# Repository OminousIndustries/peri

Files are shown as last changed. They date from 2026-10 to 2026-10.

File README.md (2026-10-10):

<h1 align="center">Peri</h1>

<p align="center"><em>Someone to talk to.</em></p>

<p align="center">
  <a href="docs/PARTS.md">Parts</a> ·
  <a href="prints/README.md">Print files</a> ·
  <a href="docs/ASSEMBLY.md">Assembly</a> ·
  <a href="device/INSTALL.md">Setup</a> ·
  <a href="docs/USE.md">Using Peri</a>
</p>

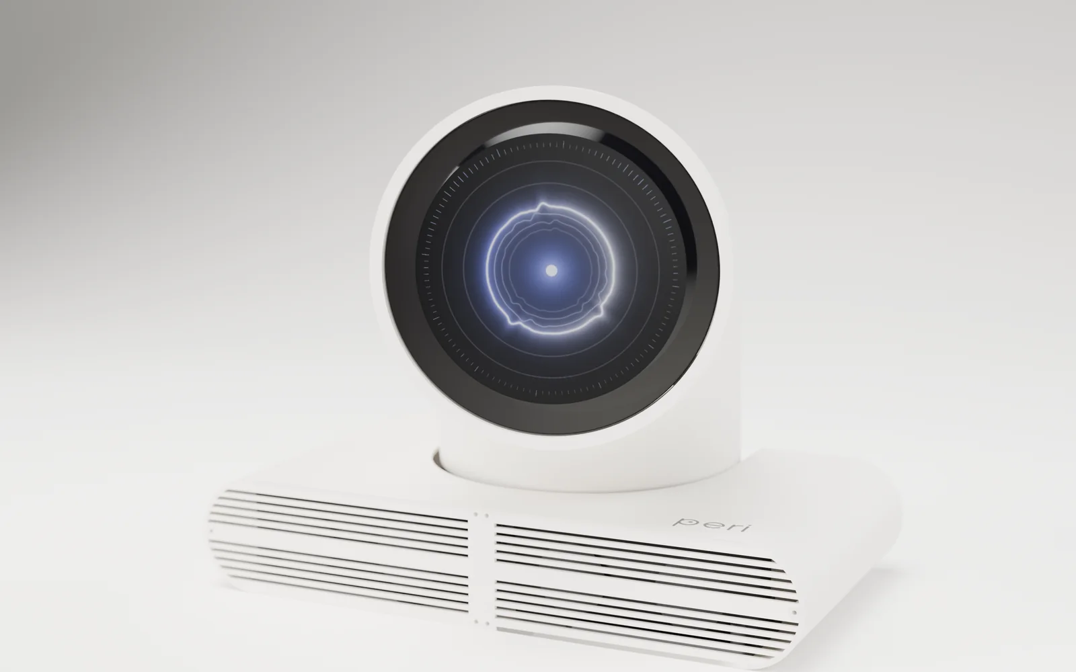
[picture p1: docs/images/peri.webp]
Product render of Peri in a warm white shell, with a glowing round display and twin speaker grilles.


<p align="center">Print it. Build it. Start a conversation.</p>

## Make it yours

Print the same case in your choice of filament. These renders show Porcelain, Graphite, Ember and Periwinkle.

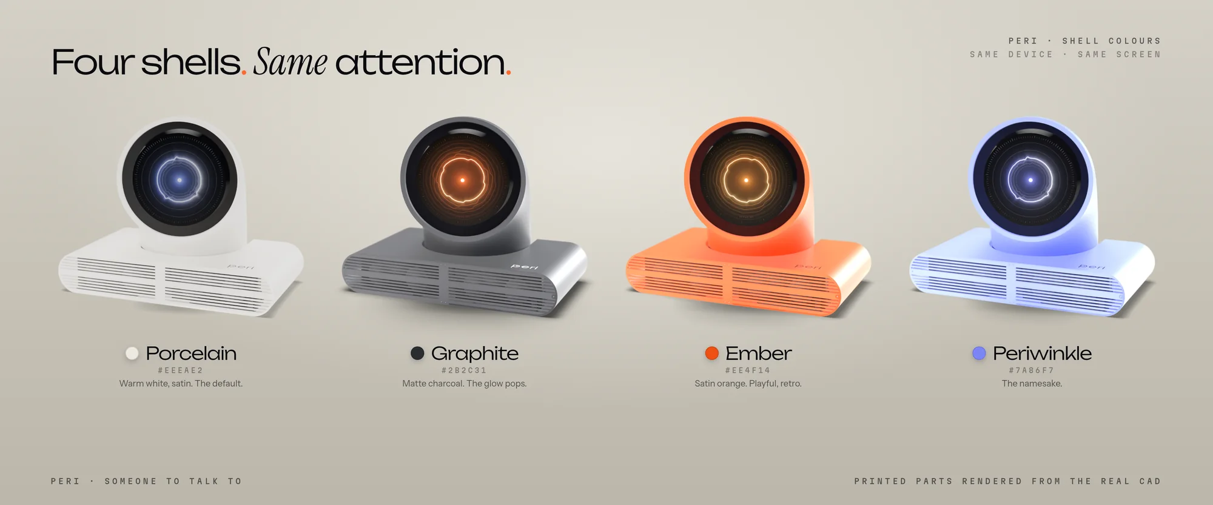
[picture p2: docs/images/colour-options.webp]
Peri rendered in four shell colours: warm white, charcoal, orange and periwinkle.


## From the inside out

An exploded render of the enclosure, neck mechanism, display and speakers. Use the [illustrated assembly guides](docs/ASSEMBLY.md) for the build sequence and wiring.

<p align="center">
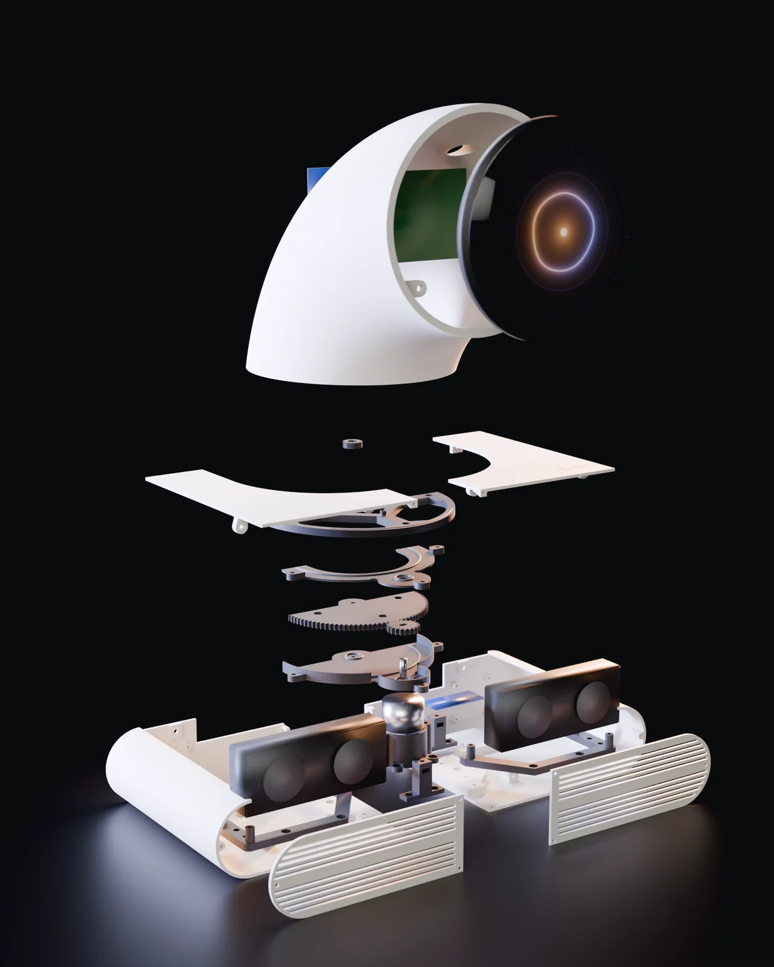
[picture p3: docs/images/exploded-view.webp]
Exploded render showing Peri's display and head shell above the neck, gears, base and two speaker enclosures.
  
</p>

## A little company

Tap the display to wake Peri and start talking. Hold it to choose a voice, adjust the volume or change its personality.

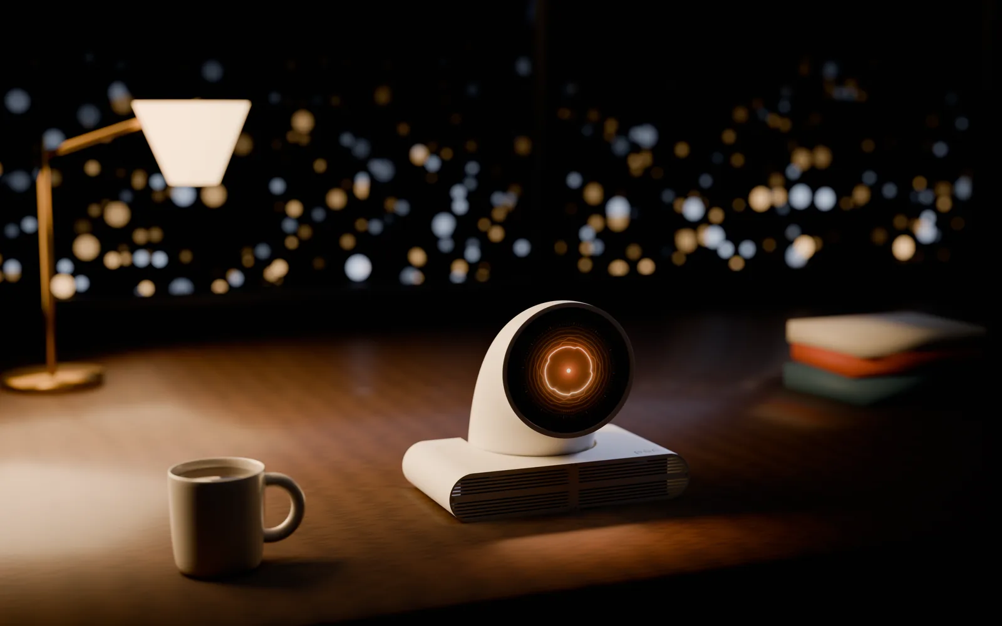
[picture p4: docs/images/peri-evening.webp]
Lifestyle render of Peri on a warmly lit desk beside a lamp, books and a mug.


*Product renders from the Peri website. Follow the assembly guides for the actual parts and wiring.*

## Build one

A 3D-printed voice chatbot built with a Raspberry Pi 4B, a round touch display and a WM8960 audio HAT with two speakers. The Arduino and motor are **optional**: the Arduino needs its own power source and does not connect to the Pi. There is no room for that USB connection inside the enclosure.

Download this repository with **Code → Download ZIP**, then follow these steps:

1. **[Get the parts](docs/PARTS.md)** — electronics, speakers, screws and tools.
2. **[Print the case](prints/README.md)** — choose the version without an Arduino, or the optional motorized version.
3. **[Assemble and wire it](docs/ASSEMBLY.md)** — follow the [main illustrated guide](docs/AssemblyGuide.pdf); use the [Arduino mounting guide](docs/ArduinoAssemblyGuide.pdf) only for the optional motor assembly.
4. **[Install the software](device/INSTALL.md)** — set up the Pi and add your own API key. No Arduino is required for conversation.
5. **[Use Peri](docs/USE.md)** — touch controls, settings and troubleshooting.

The Pi software, speech and audio have been tested on the physical device with **Raspberry Pi OS (Legacy) 64-bit, released 2024-07-04**. **Head movement has not been verified:** the Arduino had no power during that test.

Conversation requires internet access and your own OpenAI API account. API usage is billed separately. Audio is sent to OpenAI while Peri is awake and its microphone is enabled.

## Experimental

### Head movement

For builders who want a moving head, the [standalone sweep sketch](device/firmware/README.md) runs on the separately powered Arduino: **left → pause → middle → pause → right → pause → middle → pause**, repeating automatically. It starts with a small, estimated ±5° sweep. It is independent of speech and the Pi, and has **not been physically verified**. The guide covers wiring, uploading and checking clearance.

### Your own local AI

Want Peri to use the models and voices on your home server? **Local LLM, speech-to-text and text-to-speech support is not implemented yet**, but the code is here to adapt to your own setup with a coding agent. The [local AI guide](docs/LOCAL_AI.md) maps the integration points and includes a starter prompt for your agent. This takes code changes; it is not an existing settings toggle.

## Files

| Folder | What you need it for |
|---|---|
| [prints/](prints/) | STL files and print quantities |
| [docs/](docs/) | Parts list, illustrated assembly guides and everyday use |
| [device/](device/) | Pi software, installer, display interface and experimental motor firmware |

Personal and noncommercial use is permitted under the [project licenses](LICENSE.md). Commercial use requires separate permission. Third-party fonts retain their [own licenses](THIRD_PARTY_NOTICES.md).

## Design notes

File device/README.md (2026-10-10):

# Peri software

This folder contains the software installed on the Raspberry Pi. The standard build runs without an Arduino; an optional Arduino uses separate power and does not connect to the Pi.

Start with **[INSTALL.md](INSTALL.md)**. For touch controls and settings, see **[Using Peri](../docs/USE.md)**.

- `server/` — Python server and device controls.
- `web/` — the round display's interface.
- `firmware/` — experimental standalone sweep and serial-controlled Nano sketches; [start here](firmware/README.md).
- `scripts/`, `systemd/`, `assets/` — installation, startup and diagnostics.
- `config/` — default settings and an API-key configuration example.

Run the installer on the Pi. Keep your API key in `/etc/peri/peri.env`; no key is included here.

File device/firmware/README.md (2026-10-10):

# Experimental head movement

Head movement is optional and **has not been verified on the physical Peri**. The Arduino needs separate power and does not connect to the Pi: there is no room for that USB connection in the enclosure. The Pi's voice, display and audio features work without it.

## Standalone sweep

Use [peri_sweep/peri_sweep.ino](peri_sweep/peri_sweep.ino) for the experimental, independently powered build. It uses only the Arduino core, with no extra libraries or serial commands.

After a three-second startup pause, it repeats:

**Left → pause → middle → pause → right → pause → middle → pause.**

The default is an estimated **±5°** of neck movement, with two-second pauses and a slow step rate. The estimate uses the existing project's nominal motor and gear ratio; actual direction, travel and clearances need a physical check. The coils turn off during each pause to avoid continuous holding current.

The sketch compiles for Nano ATmega328P and Old Bootloader targets. A host simulation checked 1,000 cycles with each direction setting, including the sequence, pauses, coil release and step-count bounds. These checks do not verify physical motion or prevent lost steps on real hardware.

## Wiring and power

For a classic ATmega328P Nano, ULN2003 board and **5 V** 28BYJ-48 motor:

| Connection | Connect to |
|---|---|
| ULN2003 IN1 | Nano D8 |
| ULN2003 IN2 | Nano D9 |
| ULN2003 IN3 | Nano D10 |
| ULN2003 IN4 | Nano D11 |
| ULN2003 VCC / + | Separate regulated 5 V motor supply |
| ULN2003 GND / − | Supply ground and Nano GND |
| ULN2003 motor socket | Keyed five-wire motor plug |

Power the Nano from its own USB supply, or an appropriate regulated supply for your exact board. A shared external supply may power the Nano and driver if correctly wired and rated for both; the motor current should go directly to the driver, not through Nano I/O pins. Follow the [classic Nano power specifications](https://store.arduino.cc/products/arduino-nano) and check clone-board differences. A regulated 5 V feed is not a VIN feed. No power or data connection to the Pi is required.

## Upload from your computer

1. With the motor supply disconnected, connect the Nano to your computer using a USB data cable.
2. Open `peri_sweep/peri_sweep.ino` in Arduino IDE. Select **Arduino AVR Boards → Arduino Nano**, the matching processor/bootloader and its USB port. Some clones require **ATmega328P (Old Bootloader)**.
3. Upload the sketch, then disconnect the programming cable. Do not connect an external power feed while programming unless your board's power arrangement explicitly supports it.
4. With **all power off**, gently center the neck and check cable slack. The sketch assumes this starting position is the middle; it cannot home itself or detect an end stop.
5. Keep the separate supply switch accessible, clear the mechanism and apply power. It starts moving automatically after three seconds, even with the Pi off. Disconnect that supply immediately if it binds or moves unexpectedly.

The settings near the top of the sketch control sweep angle, pauses, step interval and direction. Re-upload after changes. Keep the small default range until you have measured clearance. Recenter with power off after every reset, power interruption, skipped step or manual movement; pauses release the coils, so position can be disturbed.

Keep `PERI_HEAD_DRIVER=none` on the Pi. Its settings, speech and shutdown commands cannot control or stop this independent sweep. Switch off the Arduino supply separately.

## Existing serial sketch — custom setups only

[peri_head/peri_head.ino](peri_head/peri_head.ino) is a separate serial-controlled experiment. It waits for commands and will not sweep from power alone. It is retained for custom hardware with a real USB data connection to a host outside the standard enclosure arrangement.

The existing `scripts/flash-firmware.sh` uploads **that serial sketch**, not `peri_sweep`. Do not run it for the standalone build. Upload the sweep sketch from your computer as described above.

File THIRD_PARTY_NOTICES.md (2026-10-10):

# Third-party notices

The display interface includes these fonts under the SIL Open Font License 1.1. Their license files are included alongside the fonts:

| Font | License |
|---|---|
| Instrument Sans | [OFL](device/web/fonts/OFL-instrumentsans.txt) |
| Instrument Serif | [OFL](device/web/fonts/OFL-instrumentserif.txt) |
| Martian Mono | [OFL](device/web/fonts/OFL-martianmono.txt) |
| Unbounded | [OFL](device/web/fonts/OFL-unbounded.txt) |

Raspberry Pi OS, Python packages, Chromium, Arduino tooling and vendor drivers retain their own licenses. They are installed separately and are not relicensed by this project.

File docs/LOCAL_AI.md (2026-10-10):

# Bring your own local AI stack

**Not implemented yet.** This is a starting point for adapting Peri with a coding agent to the LLM, speech recognition and text-to-speech services you already run at home. There is no local-backend switch or ready-made offline installer in this release.

The current software uses OpenAI Realtime for conversation and speech. A local text-generation endpoint alone cannot replace that whole connection: Peri also needs microphone transport, transcription, speech playback, turn detection and interruption handling.

## A practical starting design

Keep the Pi as the display, microphone and speaker device. Let a computer or server on your home network run the models:

```text
Peri microphone → local speech-to-text → local LLM → local text-to-speech → Peri speakers
                         ↕                  ↕                ↕
                     transcripts       conversation     speaking/finished
                         └──────────── Peri display ─────────┘
```

Running everything on the Pi 4B would need separate performance testing. For a first version, use one complete spoken turn at a time and tap-to-interrupt; add streaming or voice interruption once the basic path works.

## Give your coding agent these details

- **LLM:** server URL, API format, model name, authentication and whether it streams responses.
- **Speech-to-text:** endpoint, accepted audio format/sample rate, language and how it signals a completed transcript.
- **Text-to-speech:** endpoint, voice, output format/sample rate and whether it streams audio.
- **Host:** where each service runs and how the Pi reaches it over the home network.
- **Conversation:** how to detect the end of speech, maintain history, cancel a reply and handle unavailable services.

Use environment variables for any credentials. Decide explicitly whether local mode may ever fall back to a cloud service; for a local-only build, disable cloud fallback and verify that audio and requests stay on the intended hosts.

## Where to adapt the code

| Area | Starting files | Work needed |
|---|---|---|
| Audio connection | [realtime.js](../device/web/js/realtime.js), [audio.js](../device/web/js/audio.js) | Replace or adapt the WebRTC connection, microphone transport and returned audio playback |
| Conversation and display | [agent.js](../device/web/js/agent.js) | Map local transcripts and listening/thinking/speaking events; preserve tap, mute, sleep and cancellation |
| Server endpoints | [routes/api.py](../device/server/peri_server/routes/api.py), [openai_client.py](../device/server/peri_server/openai_client.py), [context.py](../device/server/peri_server/context.py) | Add a backend adapter for local services and remove the OpenAI-key requirement from that local path |
| Persona and session | [session.py](../device/server/peri_server/session.py), [catalog.py](../device/server/peri_server/catalog.py) | Reuse personality instructions and adapt conversation history/tool handling to the selected LLM |
| Configuration and controls | [config.py](../device/server/peri_server/config.py), [settings.py](../device/server/peri_server/settings.py), [constants.py](../device/server/peri_server/constants.py), [settings.js](../device/web/js/settings.js) | Add backend selection and service endpoints; replace cloud-specific model/voice choices in local mode |
| Diagnostics | [verify.sh](../device/scripts/verify.sh), [diag.js](../device/web/js/diag.js) | Check the selected local services instead of requiring OpenAI credentials/reachability |

`PERI_OPENAI_BASE_URL` exists, but the current client still calls Realtime endpoints and the interface expects Realtime events. Pointing it at an ordinary local chat-completions server is not a working local-AI implementation.

## A prompt to get started

Copy this into your coding agent, then provide your actual service details:

> Adapt this Peri repository to my home AI stack. Local AI is not currently implemented. First inspect docs/LOCAL_AI.md and the current browser/server audio flow, then ask for my LLM, speech-to-text and text-to-speech endpoint formats, model/voice names, authentication and sample rates. Add an explicit local backend while preserving the existing OpenAI option. Keep model inference on my chosen home server and the Pi as the audio/display device. Start with complete speech turns and tap-to-interrupt. Preserve tap-to-wake, microphone mute, sleep, captions, personality and listening/thinking/speaking display states. Make cancellation stop both generation and queued audio, and prevent stale replies after sleeping or reconnecting. Keep credentials on the server. Local mode must work without an OpenAI key and must not silently fall back to cloud services. Keep PERI_HEAD_DRIVER=none; the optional Arduino is independent. Add focused tests with mock services, document setup for my actual stack, and distinguish automated checks from physical microphone/speaker tests.

## What to verify on your build

Check a full microphone → transcript → reply → spoken-audio round trip, then test mute, sleep, interruption and a second conversation. Disconnect each local service to confirm understandable errors and recovery. Check for speaker feedback, delayed/stale audio, correct sample rates and acceptable latency on the real Pi. If you want offline operation, also test with the internet disconnected after installing the models and dependencies.

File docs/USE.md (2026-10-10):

# Using Peri

After [setup](../device/INSTALL.md), Peri starts automatically when the Pi boots.

## Touch controls

| Action | Result |
|---|---|
| Tap while asleep | Wake Peri, then speak |
| Tap while Peri is speaking | Interrupt its reply |
| Tap while awake and not speaking | Mute or unmute the microphone |
| Double-tap while awake | Put Peri to sleep |
| Hold the display for about one second | Open settings |

Peri returns to sleep after the idle period selected in settings. There is no wake-word detector.

## Settings

Hold the display to change volume, personality, voice, captions, brightness, display rotation and sleep timing. Opening settings puts the conversation to sleep.

**Wake** lets you choose tap-to-talk or always listening. Audio goes to OpenAI while Peri is awake and its microphone is enabled. Leave tap-to-talk selected if you want to choose when a conversation begins.

If Peri hears its own speaker and interrupts itself, reduce the volume and set **Talk over Peri → Tap only**. You can still interrupt a reply by tapping.

The standard setup hides **Head movement** settings with `PERI_HEAD_DRIVER=none`. An optional Arduino is independently powered and has no connection to the Pi, so the display cannot control its movement. If head settings appear after an older installation, run `sudo peri-config set PERI_HEAD_DRIVER none` on the Pi.

## Shut down

Open settings, find **Power → Shut down**, and tap again to confirm. Wait for the Pi to shut down before unplugging it. You can also run `sudo shutdown -h now` over SSH.

If you fitted an Arduino, turn off its separate supply too. Shutting down the Pi does not switch it off.

## Get help

Start with [troubleshooting](../device/docs/TROUBLESHOOTING.md). These commands run on the Pi:

```bash
sudo peri-config status
sudo /opt/peri/scripts/verify.sh
sudo journalctl -u peri-server -u peri-kiosk -n 80 --no-pager
```

When reporting a problem, include the Pi model, OS, what happened and the relevant error. Remove API keys, passwords and network details from anything you share.

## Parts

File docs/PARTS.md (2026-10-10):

# Parts list

Parts for the Raspberry Pi 4B build shown in the assembly guides. The Arduino and motor are optional and have their own power source.

## Electronics and cables

| Quantity | Part | Fit/setup notes |
|---|---|---|
| 1 | Raspberry Pi 4B | Reference case and guide use this board; Pi 3/5 fit and cabling need separate checks |
| 1 | Waveshare **4inch DSI LCD (C)** | Round, 720×720, capacitive touch; use its mounting screws, DSI ribbon and 4-pin power/I2C lead |
| 1 | [Waveshare WM8960 Audio HAT](https://www.waveshare.com/product/wm8960-audio-hat.htm), SKU 15668 | 40-pin GPIO HAT, stereo microphones and speaker outputs; available separately or bundled with speakers |
| 2 speaker enclosures total | [Waveshare 14595, 8Ω 5W speakers](https://www.waveshare.com/product/accessories/8ohm-5w-speaker.htm) | Left/right enclosures used in the owner's tested build; supplied with that HAT kit, also available separately |
| 1 | Pi 4 compatible USB-C supply | Powers the Pi, display and audio HAT; use the right-angle USB-C adapter |
| 1 | Right-angle USB-C adapter | Compare orientation with PDF pages 18 and 23 |
| 1 | microSD card | Room for a 64-bit OS and updates; 32 GB is a practical starting size |
| 1 | Network connection | Wi-Fi or Ethernet with internet |

Compare the [display manufacturer's connections](https://www.waveshare.com/wiki/4inch_DSI_LCD_(C)) and [audio HAT documentation](https://www.waveshare.com/wiki/WM8960_Audio_HAT) with your board revision. The HAT uses I2C on BCM 2/3 and I2S on BCM 18/19/20/21; its bridge speaker outputs must not be connected to a common ground.

You need two speaker enclosures total. Some WM8960 HAT kits include both, so check the package contents before ordering additional speakers. The 5 W figure is the speaker rating; the HAT's specified output is 1 W per channel into 8Ω.

## Optional Arduino and motor

The Arduino does **not** connect to the Pi: the enclosure has no room for that USB connection. It needs independent power and a standalone sketch to control movement. An experimental [standalone sweep sketch](../device/firmware/README.md) is included. Read its wiring and testing notes before buying these optional parts; physical head movement remains unverified.

| Quantity | Part | Fit/setup notes |
|---|---|---|
| 1 | Arduino Nano, ATmega328P/compatible | Independent motor controller |
| 1 | ULN2003 stepper-driver board | Match the five-wire motor connector |
| 1 | 28BYJ-48 **5 V** stepper | Geared motor for the Arduino pinion |
| 1 | Separate power supply for the Nano and 5 V motor/driver | Check the board's power-input requirements and the motor's current draw; not powered by the Pi |
| 1 | Nano power cable | Connector depends on the Nano and its separate supply; allow access outside the enclosure |
| 1 set | Nano/driver jumper wires | Control signals and a shared ground within the motor assembly; match the standalone sketch |

## Printed parts

See the [print quantities](../prints/README.md). Print the common parts and either `NO_Arduino/` or `Arduino_Build/`, depending on your build.

## Fasteners

The first column follows the [main guide](AssemblyGuide.pdf). The optional Arduino column substitutes the [Arduino guide](ArduinoAssemblyGuide.pdf) for its base, motor and Nano bracket steps. These totals count the pictured steps; verify fit and the hardware supplied with your display.

| Fastener | Without Arduino | Optional Arduino | Uses |
|---|---:|---:|---|
| M3×8 screws | 1 | 13 | Free pinion axle without Arduino; motor mount, posts and rear join with Arduino |
| M3×10 screws | 20 | 7 | Speaker mounts and neck; also base joins/posts without Arduino |
| M3×12 screws | 5 | 5 | Big gear/neck mount (3), rear top covers (2) |
| M3×16 screws | 3 | 3 | Gearbox top through bottom to square posts |
| M3×20 screw | 1 | 1 | Main neck pivot |
| M3×25 screws | 6 | 8 | Speaker attachments (6), optional motor (2) |
| M3 standard nuts | 33 | 35 | Base, gearbox, neck, speakers and pivot |
| M3 lock nut | 1 | 0 | Free pinion axle without Arduino |
| M4×8 screws | 3 | 3 | Display to neck |
| M2×4 screws | 6 | At least 8 | Speaker grilles (6), optional ULN2003 board (at least 2; up to 4 matching holes) |
| M2×6 screws | 0 | 2 | Optional Arduino bracket to speaker mount |
| Pi/display mounting screws | 4 | 4 | Supplied with display; thread/length not specified in guide |
| Printed speaker washers | 6 | 6 | `Speaker_WasherPRINT6x.stl` |

The Arduino pinion presses onto the motor shaft and does not use the separate M3 axle screw or lock nut.

Avoid longer substitute screws: proud gearbox-top screws can hit the neck mount. Pivot fasteners must retain the assembly while permitting free motion.

## Tools

The guides call for 1.5 mm, 2 mm, 2.5 mm and 3 mm hex keys and a Phillips screwdriver. Match the key to the actual screw head. Also have a microSD writer, computer with SSH, support-removal tools and a way to measure fit and verify wiring.

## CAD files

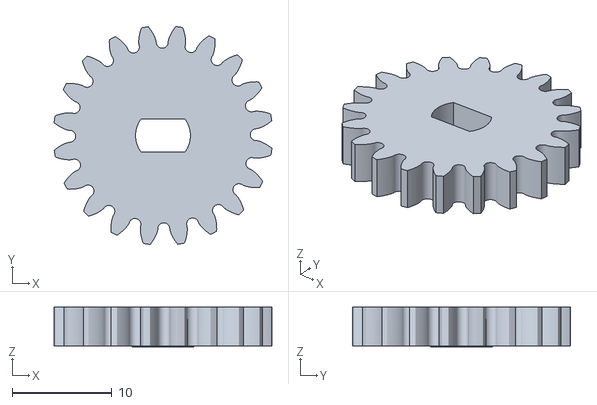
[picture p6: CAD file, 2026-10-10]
prints/Arduino_Build/Small_Gear_Arduino.stl
21.9 x 21.9 x 4.00

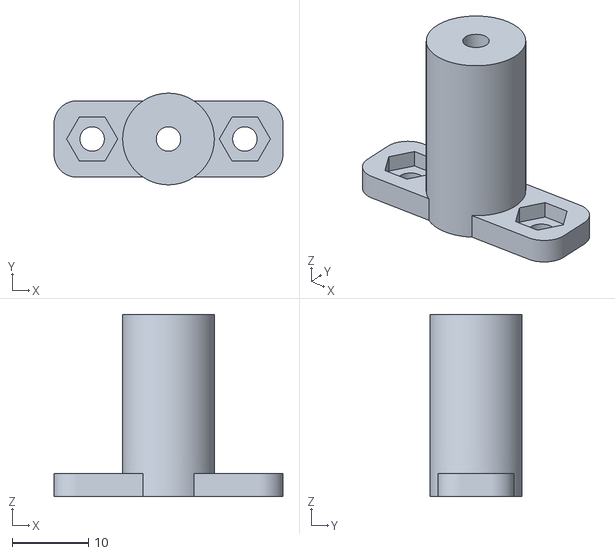
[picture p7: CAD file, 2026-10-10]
prints/Gearbox_Mount_4_Round.stl
30.0 x 12.0 x 23.9

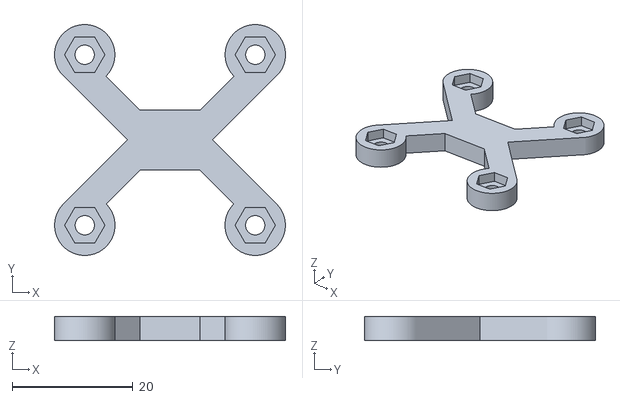
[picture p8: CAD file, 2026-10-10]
prints/NO_Arduino/X_Brace_NOARD.stl
38.2 x 38.2 x 4.00

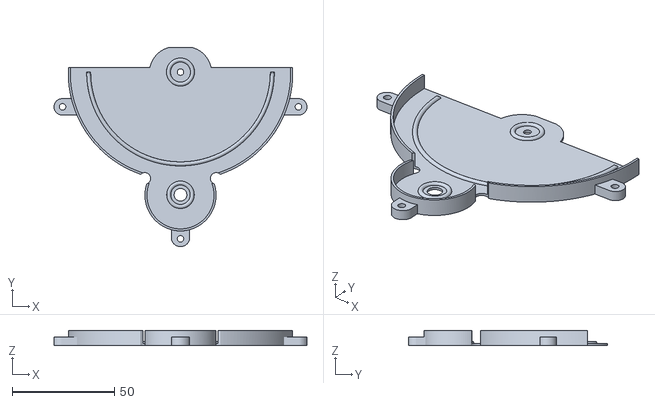
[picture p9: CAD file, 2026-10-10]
prints/Arduino_Build/Gearbox_Bottom_Arduino.stl
124.0 x 97.7 x 7.20

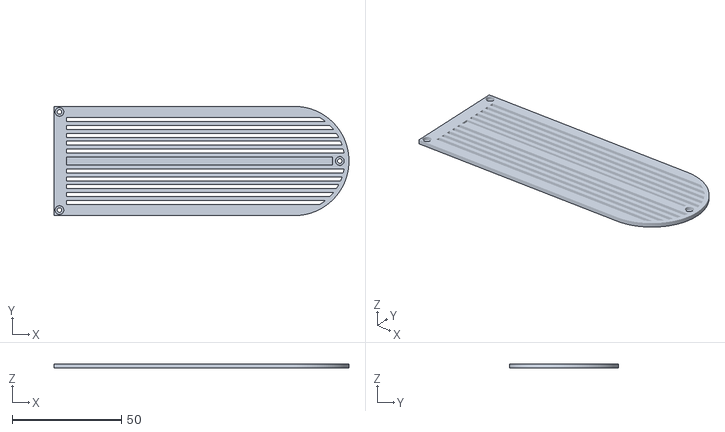
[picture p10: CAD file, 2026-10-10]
prints/Speaker_Grill_Right.stl
135.0 x 50.0 x 2.00

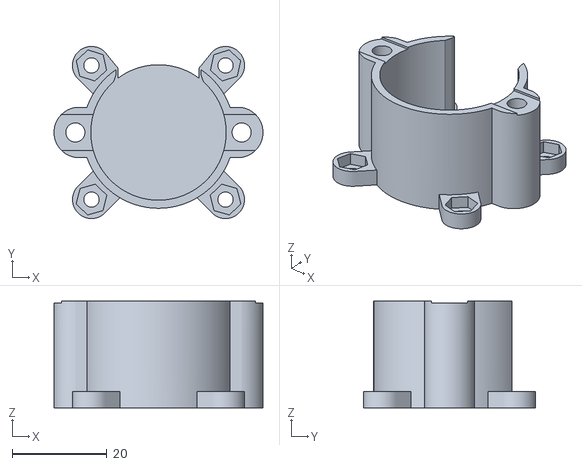
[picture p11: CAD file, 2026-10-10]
prints/Arduino_Build/Motor_Mount.stl
44.0 x 36.2 x 22.5

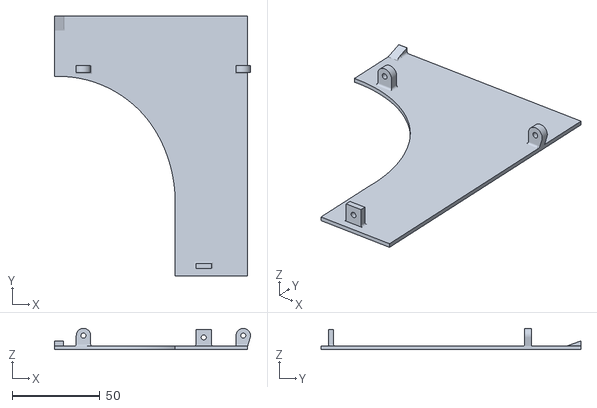
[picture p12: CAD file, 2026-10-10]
prints/Top_Cover_Right.stl
111.6 x 148.0 x 12.1

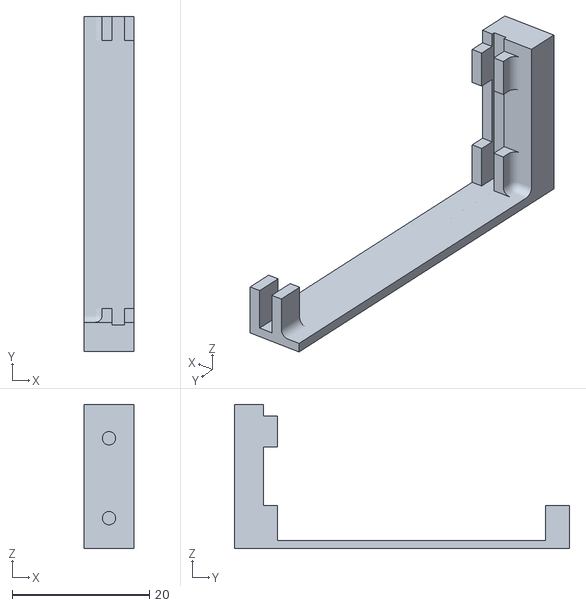
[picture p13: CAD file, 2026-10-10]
prints/Arduino_Build/Arduino_Mount.stl
7.32 x 48.9 x 21.0

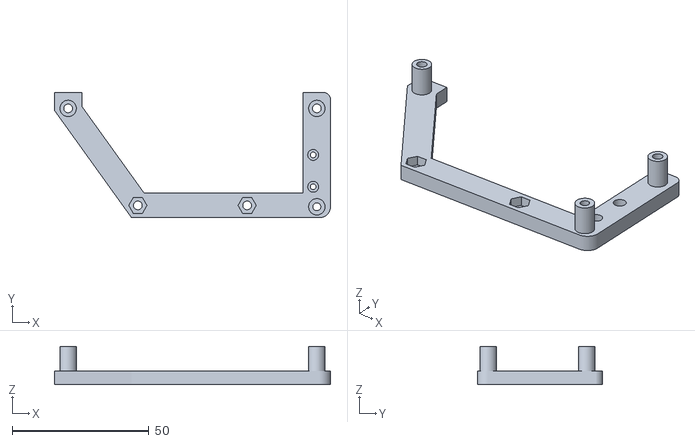
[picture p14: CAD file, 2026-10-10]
prints/Speaker_Mount_Right.stl
101.0 x 45.9 x 14.0

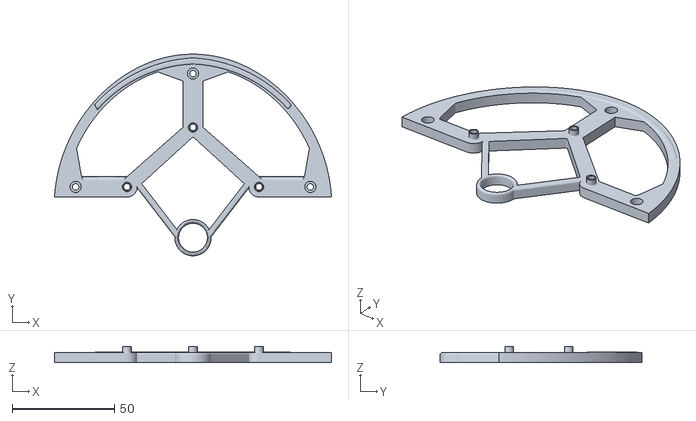
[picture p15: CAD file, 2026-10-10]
prints/Neck_Mount.stl
135.7 x 98.8 x 7.87

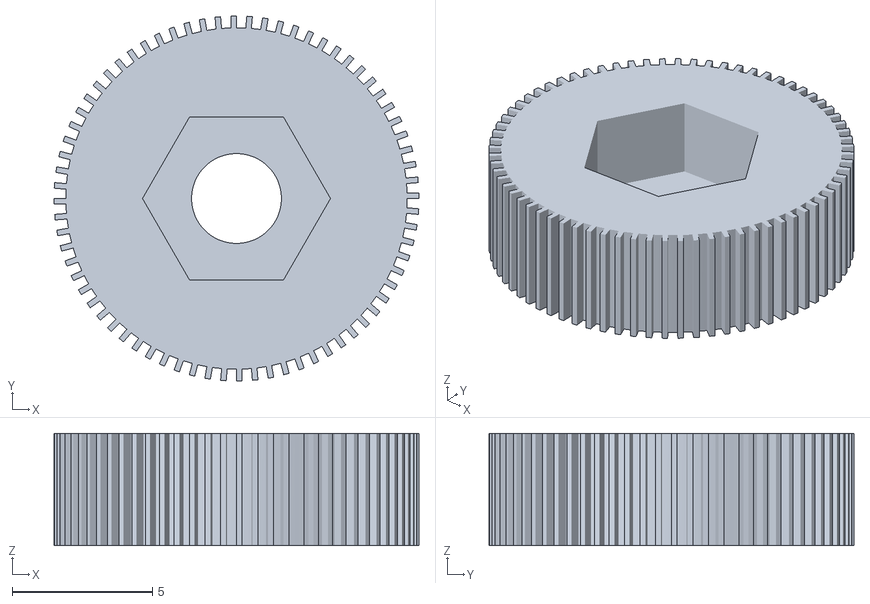
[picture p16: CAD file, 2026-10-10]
prints/Gear_Top_Cover.stl
13.0 x 13.0 x 4.00

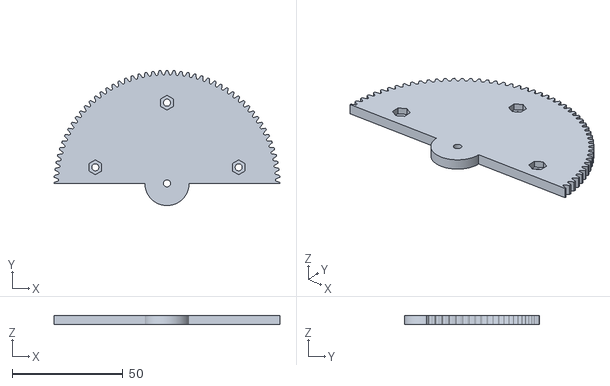
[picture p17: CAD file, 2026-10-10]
prints/Big_Gear.stl
102.0 x 61.0 x 4.00

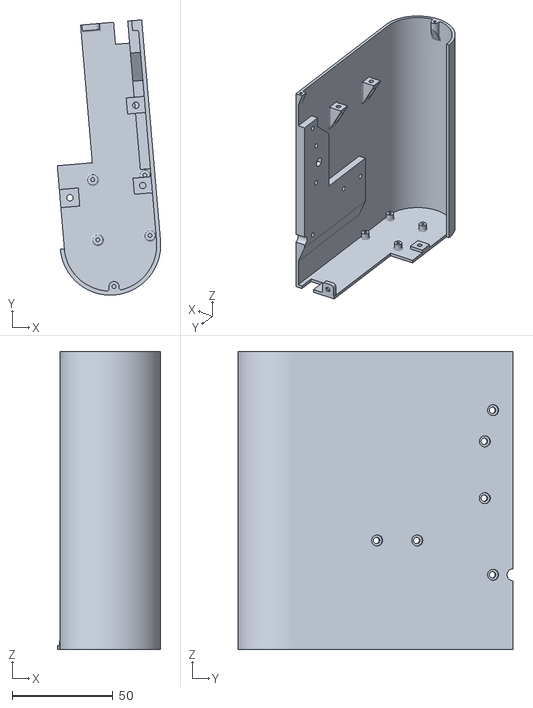
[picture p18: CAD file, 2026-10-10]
prints/Base_Left.stl
51.4 x 136.7 x 148.0

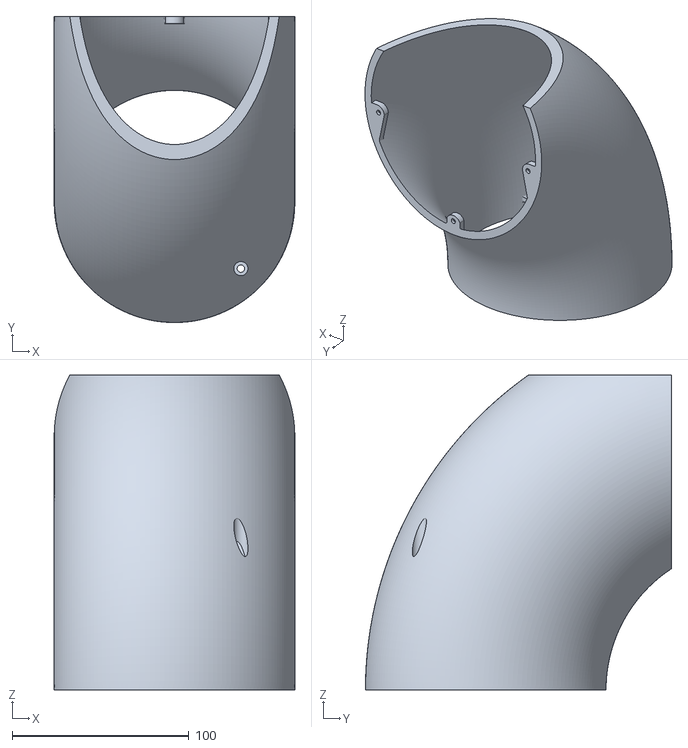
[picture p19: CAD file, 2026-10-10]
prints/Neck.stl
136.0 x 173.0 x 178.0

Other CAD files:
prints/NO_Arduino/Small_Gear_NOARD.stl
prints/NO_Arduino/Gearbox_Bottom_NOARD.stl
prints/Speaker_Mount_Left.stl
prints/Top_Cover_Left.stl
prints/Base_Right.stl
prints/Gearbox_Mount_PRINT3X.stl
prints/Gearbox_Top.stl
prints/Speaker_Grill_Left.stl
prints/Speaker_WasherPRINT6x.stl

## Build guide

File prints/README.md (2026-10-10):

# Print the parts

The 23 STL files are in this folder. They use millimeters: import at **100% / 1:1** and check dimensions in your slicer.

Print the common parts below, then choose **one** variant. The simplest build uses `NO_Arduino/`: all conversation, display and audio features work without a motor. The optional `Arduino_Build/` version adds motor mounting; its Arduino needs separate power and does not connect to the Pi.

## Common parts

| File | Quantity |
|---|---:|
| `Base_Left.stl` | 1 |
| `Base_Right.stl` | 1 |
| `Top_Cover_Left.stl` | 1 |
| `Top_Cover_Right.stl` | 1 |
| `Speaker_Grill_Left.stl` | 1 |
| `Speaker_Grill_Right.stl` | 1 |
| `Speaker_Mount_Left.stl` | 1 |
| `Speaker_Mount_Right.stl` | 1 |
| `Neck.stl` | 1 |
| `Neck_Mount.stl` | 1 |
| `Big_Gear.stl` | 1 |
| `Gearbox_Top.stl` | 1 |
| `Gear_Top_Cover.stl` | 1 |
| `Gearbox_Mount_4_Round.stl` | 1 |
| `Gearbox_Mount_PRINT3X.stl` | **3** |
| `Speaker_WasherPRINT6x.stl` | **6** |

## Without Arduino — simplest build

One each of `NO_Arduino/X_Brace_NOARD.stl`, `Gearbox_Bottom_NOARD.stl` and `Small_Gear_NOARD.stl`, plus the common parts: **26 printed pieces** total. Follow the [main illustrated guide](../docs/AssemblyGuide.pdf) and [assembly instructions](../docs/ASSEMBLY.md).

## With Arduino — optional motor assembly

One each of `Arduino_Build/Arduino_Mount.stl`, `Motor_Mount.stl`, `Gearbox_Bottom_Arduino.stl` and `Small_Gear_Arduino.stl`. This gives **27 printed pieces** including the common parts. Follow the [Arduino mounting guide](../docs/ArduinoAssemblyGuide.pdf) and [assembly instructions](../docs/ASSEMBLY.md); the [parts list](../docs/PARTS.md) includes its fasteners. Do not also print the `NO_Arduino/` parts.

Head movement is experimental and physically unverified. Read the [standalone sweep guide](../device/firmware/README.md) before choosing this version.

## Slicing and fit

Starting settings for test pieces: PLA, a 0.4 mm nozzle, 0.2 mm layers, three walls and 20–30% infill. These settings have not been validated as a complete print profile. Fit-test gears, nut pockets, posts and mating edges before printing the whole case. Gears may benefit from finer layers; settings depend on your printer and material.

Preview orientation and supports in the slicer. Some exports use a deliberate angled print frame: do not confuse that with assembled orientation. Place pieces with stable bed contact and support only where needed; inspect thin grilles, gear teeth and overhangs. Clean supports and elephant-foot edges without removing gear teeth or enlarging precision surfaces unnecessarily.

Check the dimensions of each part in your slicer before printing. The base is split into left and right halves.

Next: [assemble Peri](../docs/ASSEMBLY.md).

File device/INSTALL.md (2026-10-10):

# Set up Peri

You need the assembled Pi 4B, display, WM8960 HAT and speakers, a microSD card, internet access, and a computer that can connect to the Pi over SSH. Use your own OpenAI API key.

## 1. Prepare the Pi

The tested device used **Raspberry Pi OS (Legacy) 64-bit, release 2024-07-04 (Bullseye)** with working display and audio drivers. If you already have that working setup, keep it: the installer preserves those drivers. Avoid `apt full-upgrade` on that vendor-driver setup because a kernel change can break them.

For a new SD card, the installer also supports **Raspberry Pi OS Lite 64-bit, Bookworm or Trixie**. Those installation paths have automated checks but have not been physically verified on the reference device. A fresh stock Legacy image also needs the display and audio vendor drivers; it is not the same as an already configured device.

Use Raspberry Pi Imager to write your chosen image. Configure:

- Hostname: `peri`.
- Your own username and password. Use a username other than `peri`, which the installer reserves for its service account.
- Wi-Fi and country, if using wireless networking.
- Your timezone and keyboard layout.
- SSH enabled.

Insert the card. With the power off, check all wiring, then power on the Pi. The optional Arduino does not connect to the Pi and needs its own power source; it is not needed for this setup. The display may stay dark until the installer runs and the Pi reboots.

## 2. Copy the software

On your computer, open a terminal in the downloaded repository folder. Replace `USER` with the login you chose. If `peri.local` does not work, use the Pi's IP address.

```bash
scp -r device USER@peri.local:~/
ssh USER@peri.local
cd ~/device
```

Alternatively, copy the `device` folder into your Pi user's home folder with an SCP client, then connect over SSH and run `cd ~/device`.

## 3. Install

Run these commands **on the Pi**:

```bash
sudo bash ./install.sh --dry-run --yes --head none
sudo bash ./install.sh --yes --head none
```

The first command previews the changes. The second installs Peri, configures the display/audio and sets the interface to start at boot. `--head none` disables Pi motor control and hides its head settings, including when you have an independently powered Arduino. Wait for it to finish and resolve any `FAIL` entries. If it reports **REBOOT REQUIRED**, run:

```bash
sudo reboot
```

Reconnect with `ssh USER@peri.local` after the Pi restarts.

## 4. Add your API key

Create a key in your own [OpenAI API account](https://platform.openai.com/api-keys) and enable API billing. A ChatGPT subscription does not include API usage.

Run this block in Bash on the Pi. The key is entered without displaying it or adding it to shell history:

```bash
read -r -s -p 'OpenAI API key: ' PERI_SETUP_KEY; printf '\n'
printf '%s\n' "$PERI_SETUP_KEY" | sudo peri-config set OPENAI_API_KEY -
unset PERI_SETUP_KEY
sudo peri-config key-check
```

The key is stored in `/etc/peri/peri.env`. Keep it out of GitHub, screenshots and shared logs. `key-check` contacts OpenAI to check the key.

## 5. Optional Arduino

**No Arduino flashing or Pi connection is needed for the normal build.** The enclosure has no room for a USB connection between the Pi and Nano. If you fit the optional motor assembly, its Arduino needs separate power and a standalone movement sketch. See the [assembly instructions](../docs/ASSEMBLY.md#7-optional-arduino-power-and-firmware).

For optional movement, upload the [experimental standalone sweep sketch](firmware/README.md) from your computer, following its separate guide. Do not use the Pi flashing helper: it uploads the other, serial-controlled sketch. Head movement remains physically unverified.

If you used the earlier instructions, disable Pi motor control with:

```bash
sudo peri-config set PERI_HEAD_DRIVER none
```

## 6. Check the finished device

```bash
sudo /opt/peri/scripts/post-reboot-verify.sh
sudo /opt/peri/scripts/audio-test.sh
```

Check that the display appears after boot, touch works, both speakers play and the microphone hears you. Tap the face and try a conversation. Any optional Arduino movement needs its own power and testing; it is not controlled or verified by the Pi.

Next: **[Using Peri](../docs/USE.md)**. If something fails, use [troubleshooting](docs/TROUBLESHOOTING.md).

## Update or remove

To update, copy the new `device` folder to the Pi again, then run `cd ~/device` and `sudo bash ./install.sh --yes --head none`. The installed API key and other settings are retained.

To uninstall, run `sudo bash /opt/peri/uninstall.sh --yes`, then reboot. The uninstaller restores backed-up system files and keeps settings and credentials unless you explicitly request data removal.

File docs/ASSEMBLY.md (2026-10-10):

# Assembly and wiring

Use this with the [34-page main illustrated guide](AssemblyGuide.pdf). The PDFs use the original name Talk Buddy for this enclosure; install the current [Peri software](../device/INSTALL.md) for the Pi.

**The Arduino is optional and does not connect to the Pi.** There is no room for a Pi-to-Nano USB connection inside this enclosure. The optional Arduino and motor assembly needs separate power; speech, audio and the display work without it.

For the simplest build, use `NO_Arduino/` and the main guide throughout. For the optional motor assembly, use `Arduino_Build/` and the [13-page Arduino mounting guide](ArduinoAssemblyGuide.pdf) in place of the early crossmember, post and pinion steps. Do not combine the free pinion's pivot screw with the Arduino motor-shaft pinion. Read the [experimental standalone sweep guide](../device/firmware/README.md) first; physical head movement remains unverified.

Disconnect all power before connecting or repositioning hardware. Read the [parts list](PARTS.md) and [printing guide](../prints/README.md) first.

## 1. Base and supports

### Without Arduino — main pages 2–6

1. Attach the two speaker mounts to the matching case halves using four M3×10 screws and four M3 nuts. Check their direction against page 2.
2. Join the halves with `NO_Arduino/X_Brace_NOARD.stl`, four M3×10 screws and four M3 nuts. Leave these loose initially.
3. Fit three square posts and one round post using eight M3×10 screws and eight M3 nuts. The round post goes at the rear center pivot.
4. Join the rear tabs with one M3×10 screw and one M3 nut. Align both halves, then tighten the base joins.

### Optional Arduino — main page 2; Arduino pages 1–6

1. Attach each speaker mount to its matching base half, using four M3×10 screws and four M3 nuts total. Compare mount direction with main page 2.
2. Mount the ULN2003 board in the position shown on Arduino page 1, using at least two M2×4 screws. Board hole patterns vary; use the matching mounting holes without bending the board.
3. Insert two M3 nuts into the motor screw recesses in the case halves (Arduino page 2). These must be in place before the motor mount covers them.
4. Join the halves with `Arduino_Build/Motor_Mount.stl`, using four M3×8 screws and four M3 nuts. Leave these loose initially.
5. Fit three square posts and one round post with eight M3×8 screws and eight M3 nuts. Put the round post at the rear center pivot. Leave these loose initially.
6. Join the rear tabs with one M3×8 screw and one M3 nut. Align the case halves, then tighten the base joins (Arduino pages 5–6).

## 2. Gearbox

### Without Arduino — main pages 7–11

1. Fit `NO_Arduino/Small_Gear_NOARD.stl` to `NO_Arduino/Gearbox_Bottom_NOARD.stl` using one M3×8 screw and an M3 lock nut in the gear's recess. Retain it securely while allowing it to rotate freely.
2. Place this assembly over the four posts. Insert three M3 nuts into the front recesses of the square posts.
3. Secure the gearbox top through the bottom to those nuts with three M3×16 screws. Screw heads must sit below the neck mount's path.

### Optional motor and Nano mount — Arduino pages 7–13

1. Seat the stepper motor in its mount. Secure it using two M3×25 screws into the two nuts placed beneath the mount in section 1 (Arduino page 7).
2. Place `Arduino_Build/Gearbox_Bottom_Arduino.stl` over the four posts and motor. Ensure the motor shaft passes through its opening without forcing the cover (Arduino page 8).
3. Press `Arduino_Build/Small_Gear_Arduino.stl` onto the motor shaft, matching the shaft profile. This pinion has no separate pivot screw or lock nut (Arduino page 9).
4. Align the gearbox top with the bottom. Insert three M3 nuts in the front recesses of the three square posts, then secure the top through the bottom using three M3×16 screws (Arduino pages 10–11). Screw heads must not protrude above the top where the neck mount travels.
5. Attach `Arduino_Build/Arduino_Mount.stl` to the speaker mount pictured on Arduino page 12, using two M2×6 screws. Insert the Nano into the bracket as shown on page 13. Check access to the USB connector and jumper headers before closing the enclosure.

The remaining neck, display and enclosure steps are shared by both versions.

## 3. Neck and big gear — main pages 12–13

Join the neck mount to the big gear with three M3×12 screws/nuts. Join that assembly to the neck with three M3×10 screws/nuts. Follow PDF orientation and keep the cable loop accessible.

## 4. Display, Pi and HAT — main pages 14–18

Mount the Pi behind the round display with its four supplied screws. Connect the DSI ribbon with correct contact orientation and close both latches. Seat the WM8960 HAT over all 40 GPIO pins without an offset.

Main page 17 shows the display's four-wire lead through the HAT header:

| Display label | Pi signal | Physical pin |
|---|---|---:|
| SDA | BCM GPIO 2 / SDA1 | 3 |
| 5 V | 5 V supply | 4 |
| SCL | BCM GPIO 3 / SCL1 | 5 |
| GND | Ground | 6 |

Use lead labels and your revision's [Waveshare diagram](https://www.waveshare.com/wiki/4inch_DSI_LCD_(C)); do not infer connections from wire colors. BCM and physical pin numbering differ. Display and HAT share I2C.

Fit the right-angle USB-C adapter as on page 18, pointing clear of the neck.

## 5. Cables and display mounting — main pages 19–24

Route the speaker lead from the base through the neck-mount wiring loop and up the neck before fitting speakers. Connect it to the HAT speaker connector, supporting the board to avoid bending GPIO pins.

Route Pi power from the rear rectangular opening through the loop to the USB-C adapter. Leave slack for neck movement. If fitting the optional Arduino, route its separate power lead clear of the gears and leave access to its external supply. It does not plug into the Pi.

The neck uses three of the display module's four holes. Orient the Pi power port toward the corner without a neck screw hole (page 23). Start all three M4×8 screws before tightening; reach the upper screw through the rear access hole. Keep cables in the loop if removing the neck mount for access.

## 6. Covers, speakers and pivot — main pages 25–33

Fit covers with tabs behind the speaker mounts and rear case. Secure the rear with one M3×12 screw per side; no nuts are used there in the guide.

Attach each speaker with three M3×25 screws, three nuts and three printed washers. The top two attachments also retain the front cover. Connect matching left/right outputs; bridge speaker outputs must not be tied together or to ground.

Slide the big gear between gearbox top and bottom until it meshes with the pinion; the neck mount rests above the top. Insert the M3×20 pivot screw upward through the case, round post, bottom and big gear. Capture its nut in the gear top cover. Retain without binding the pivot.

Fit grilles with six M2×4 screws total. Inspect cable clearance before closing.

## 7. Optional Arduino power and firmware

Skip this section if building without an Arduino. Power the Nano and motor/driver independently of the Pi. Match the supply to the Nano's power-input requirements and the 5 V motor's current draw. The Nano and driver need a shared ground within that separate assembly.

The Arduino mounting PDF's final page refers to a separate Arduino Setup PDF. For this build, follow the [experimental sweep sketch's wiring and upload instructions](../device/firmware/README.md). Upload from your computer before final assembly, then disconnect the computer and use the separate power supply. The sweep starts automatically after a three-second pause.

Use `peri_sweep.ino` for standalone motion. The separate `peri_head.ino` sketch requires serial commands, and the Pi flashing helper uploads that serial version. The Pi cannot control this separately powered, unconnected Arduino, including through Peri's head settings.

## 8. First boot checks

- Verify DSI seating, header alignment and speaker wiring with power off.
- Check cable slack and cover clearance with a small manual sweep. Do not force gears or assume the sector gear's full arc is available.
- For the optional motor, verify wiring against its standalone sketch and center the neck with power off. There is no position sensor. Check its movement limits and cable clearance before powering it; keep hands clear during testing. Motor movement remains unverified on the reference device.

Continue with [software setup](../device/INSTALL.md). Check touch, audio and reboot on the Pi. Any optional motor test is separate from the Pi setup.

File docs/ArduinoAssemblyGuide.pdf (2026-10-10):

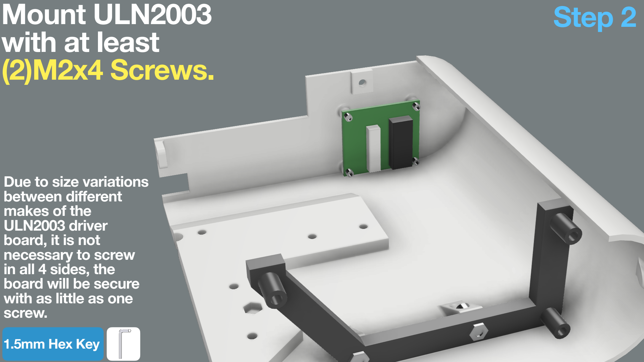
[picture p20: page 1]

Mount ULN2003
with at least
(2)M2x4 Screws.
Step 2

Due to size variations
between different
makes of the
ULN2003 driver
board, it is not
necessary to screw
in all 4 sides, the
board will be secure
with as little as one
screw.

1.5mm Hex Key

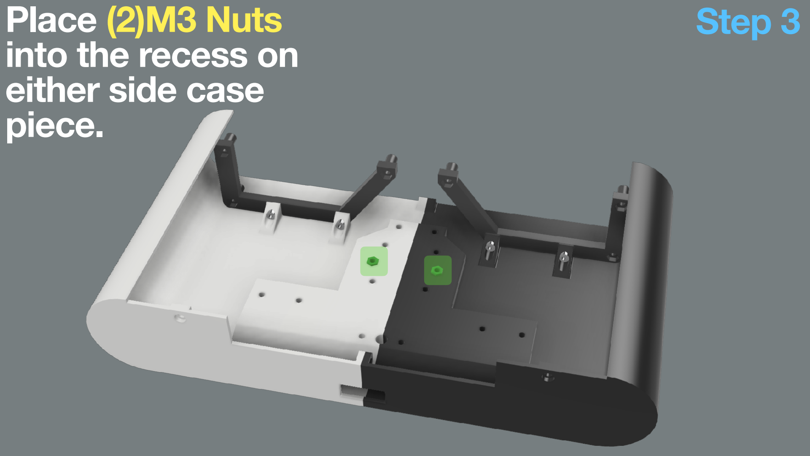
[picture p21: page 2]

Place (2)M3 Nuts
into the recess on
either side case
piece.
Step 3

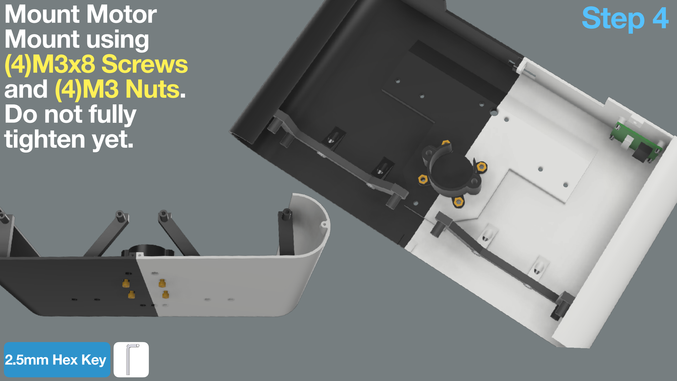
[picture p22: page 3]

Mount Motor
Mount using
(4)M3x8 Screws
and (4)M3 Nuts.
Do not fully
tighten yet.
Step 4

2.5mm Hex Key

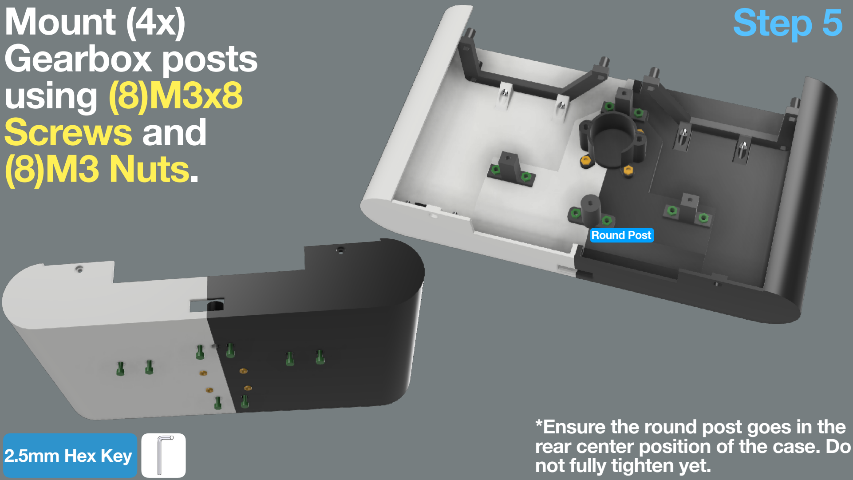
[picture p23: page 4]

Mount (4x)
Gearbox posts
using (8)M3x8
Screws and
(8)M3 Nuts.
Step 5

*Ensure the round post goes in the rear center position of the case. Do not fully tighten yet.

Round Post

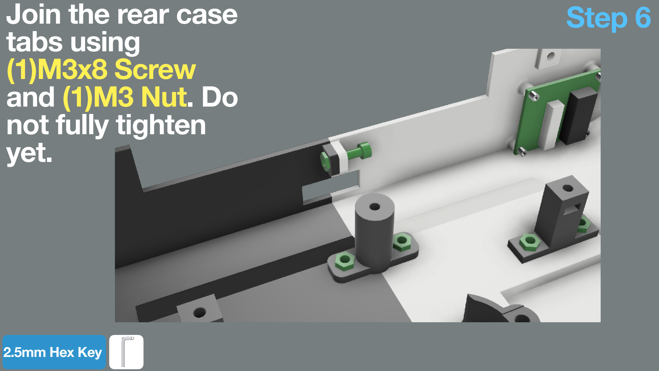
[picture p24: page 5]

Join the rear case
tabs using
(1)M3x8 Screw
and (1)M3 Nut. Do
not fully tighten
yet.
Step 6

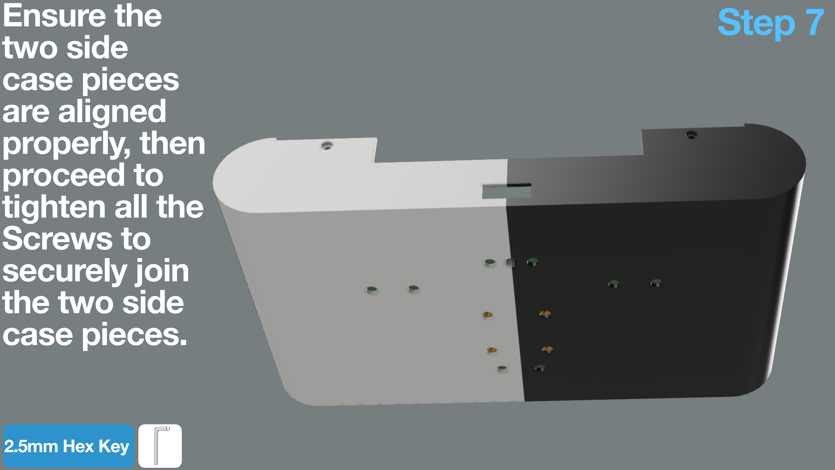
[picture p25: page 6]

Ensure the
two side
case pieces
are aligned
properly, then
proceed to
tighten all the
Screws to
securely join
the two side
case pieces.
Step 7

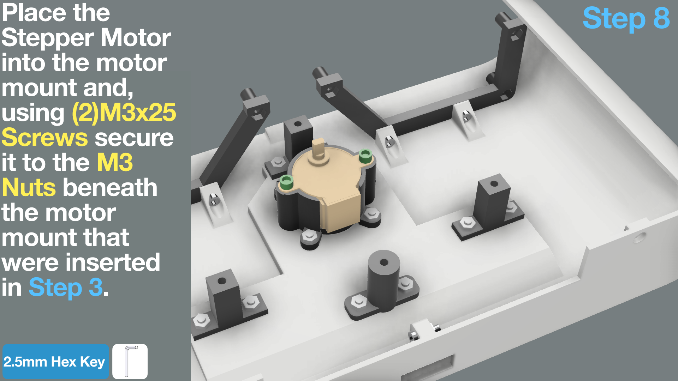
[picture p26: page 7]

Place the | Step 8 Stepper Motor
into the motor
mount and,
using (2)M3x25
Screws secure
it to the M3
Nuts beneath
the motor
mount that
were inserted
in Step 3

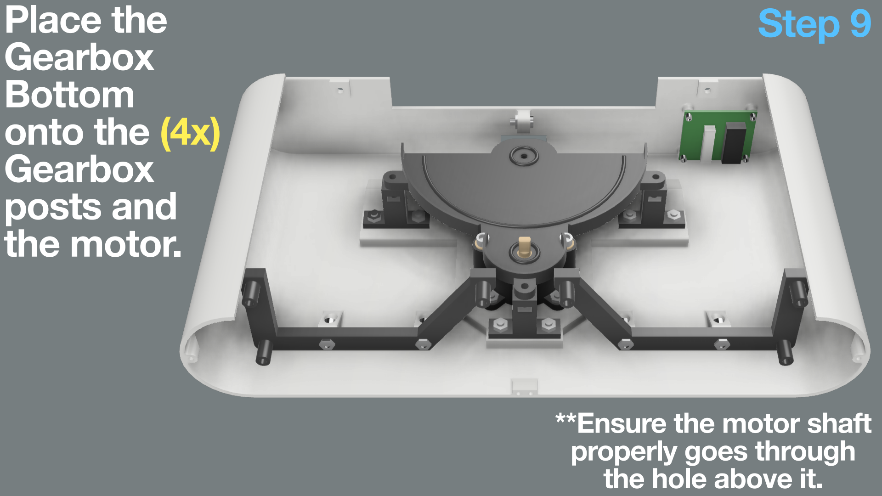
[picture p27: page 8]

Place the
Gearbox
Bottom
onto the (4x)
Gearbox
posts and
the motor.
Step 9

**Ensure the motor shaft
properly goes through
the hole above it.

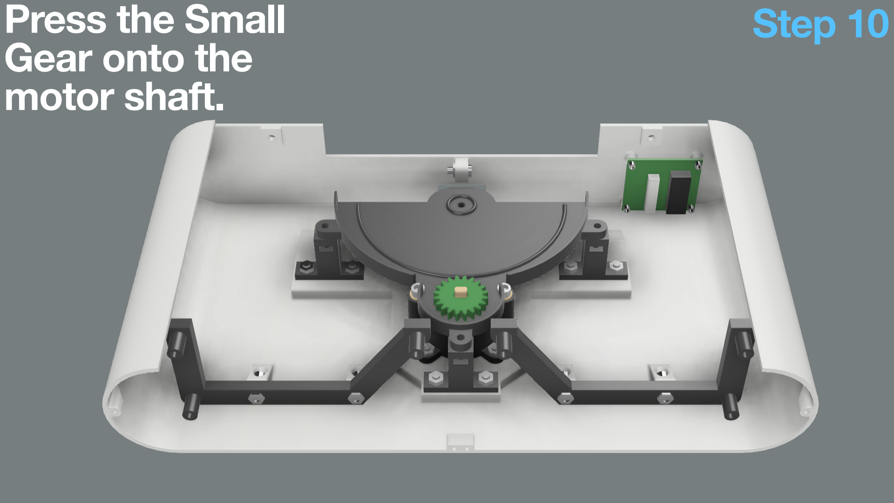
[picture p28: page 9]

Press the Small
Gear onto the
motor shaft.
Step 10

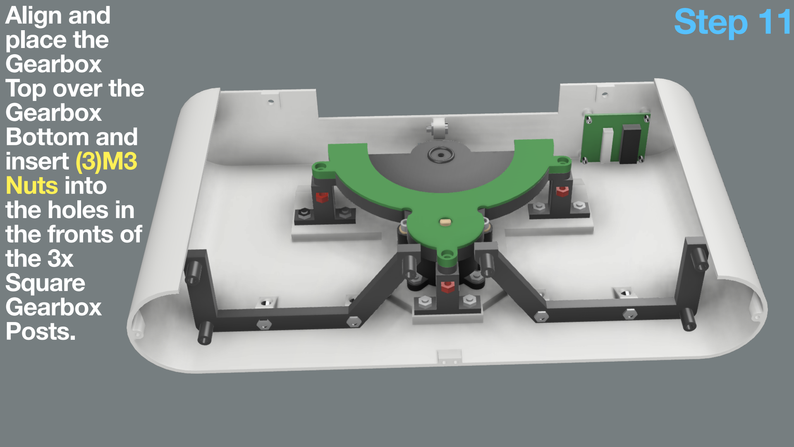
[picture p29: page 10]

Step 11 Align and
place the
Gearbox
Top over the
Gearbox
Bottom and
insert (3)M3
Nuts into
the holes in
the fronts of
the 3x
Square
Gearbox
Posts.

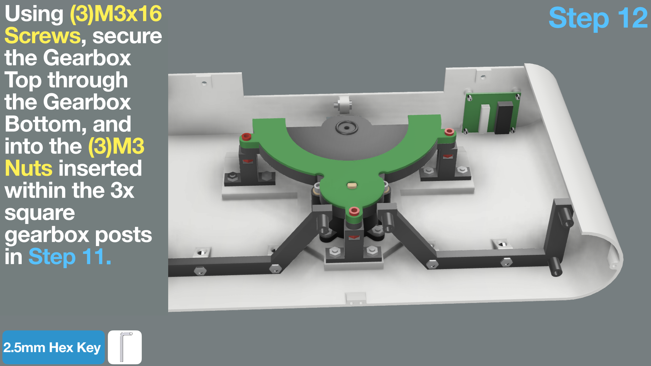
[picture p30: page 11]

Using | Step 12 ⁽³⁾M3x16
Screws, secure
the Gearbox
Top through
the Gearbox
Bottom, and
into the (3)M3
Nuts inserted
within the 3x
square
gearbox posts
in Step 11.

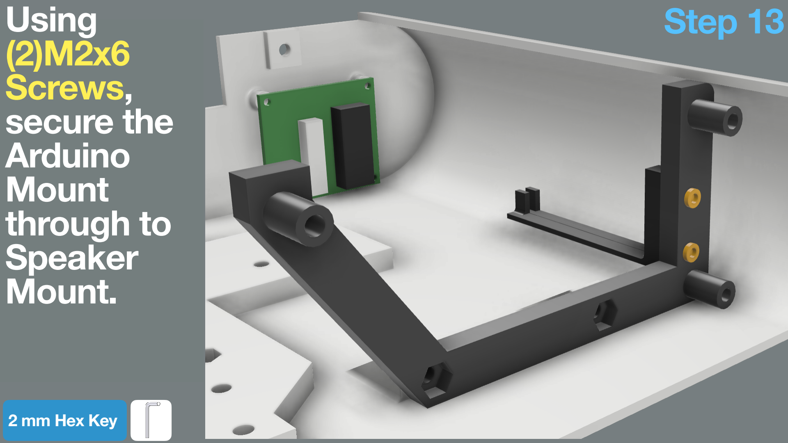
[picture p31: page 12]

Using | Step 13
(2)M2x6
Screws,
secure the
Arduino
Mount
through to
Speaker
Mount.

### 2 mm Hex Key

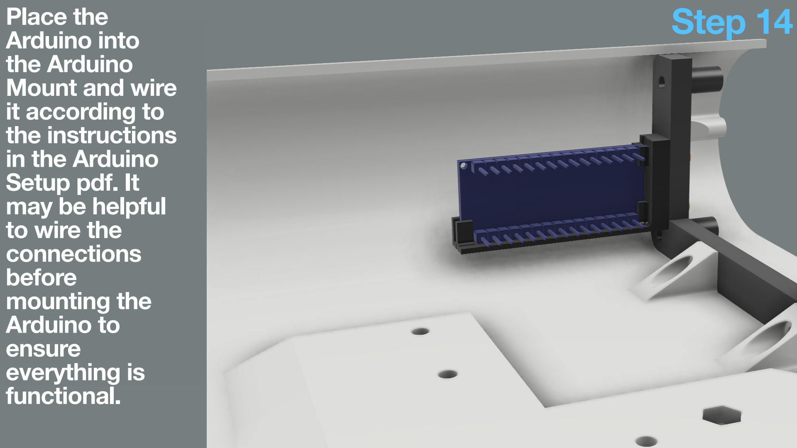
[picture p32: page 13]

Step 14 Place the
Arduino into
the Arduino
Mount and wire
it according to
the instructions
in the Arduino
Setup pdf. It
may be helpful
to wire the
connections
before
mounting the
Arduino to
ensure
everything is
functional.

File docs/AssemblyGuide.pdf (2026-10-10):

## Talk Buddy Kit Build Instructions

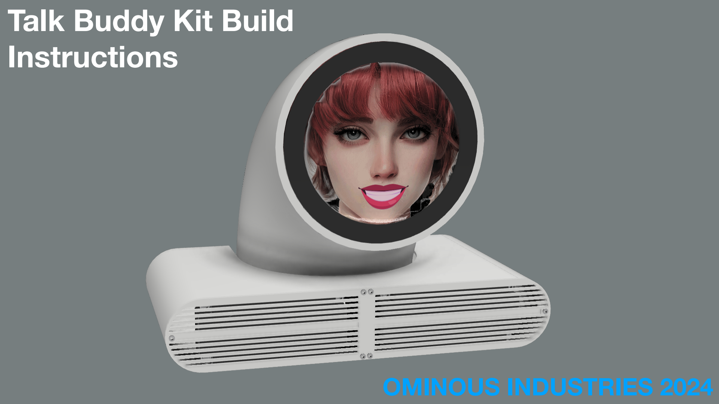
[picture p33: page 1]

### OMINOUS INDUSTRIES 2024

## Using (4)M3x10 Screws and (4)M3

## Nuts, attach the two Speaker Mounts to

either side case piece.

*Make sure the
direction of the two
Speaker Mounts is
correct

## Step 1

2.5mm Hex Key

## Step 2

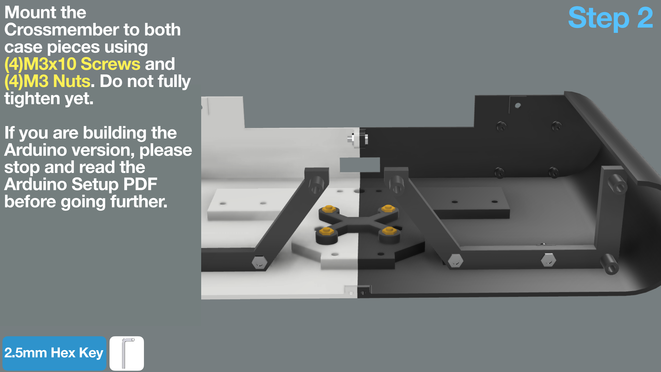
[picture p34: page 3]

Mount the
Crossmember to both
case pieces using
(4)M3x10 Screws and
(4)M3 Nuts. Do not fully
tighten yet.
If you are building the
Arduino version, please
stop and read the
Arduino Setup PDF
before going further.

## Mount (4x) Gearbox posts

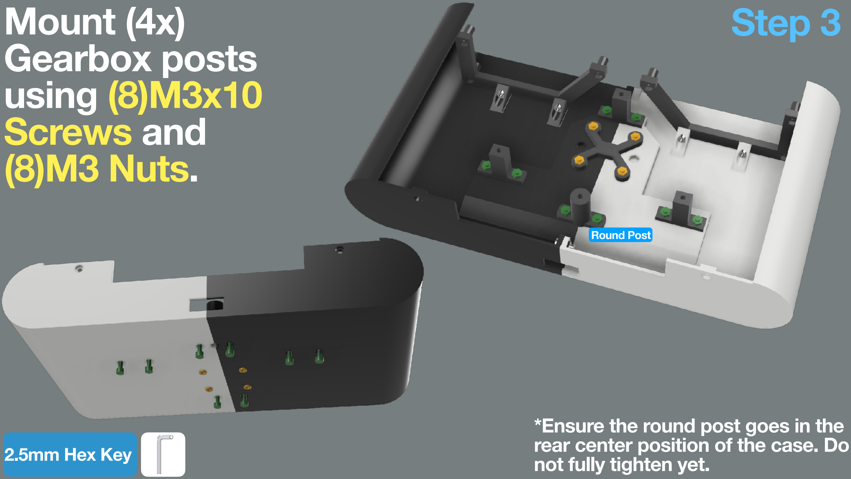
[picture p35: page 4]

## using (8)M3x10 Screws and

(8)M3 Nuts.

## Step 3

*Ensure the round post goes in the rear center position of the case. Do not fully tighten yet.

Round Post

## Join the rear case tabs using

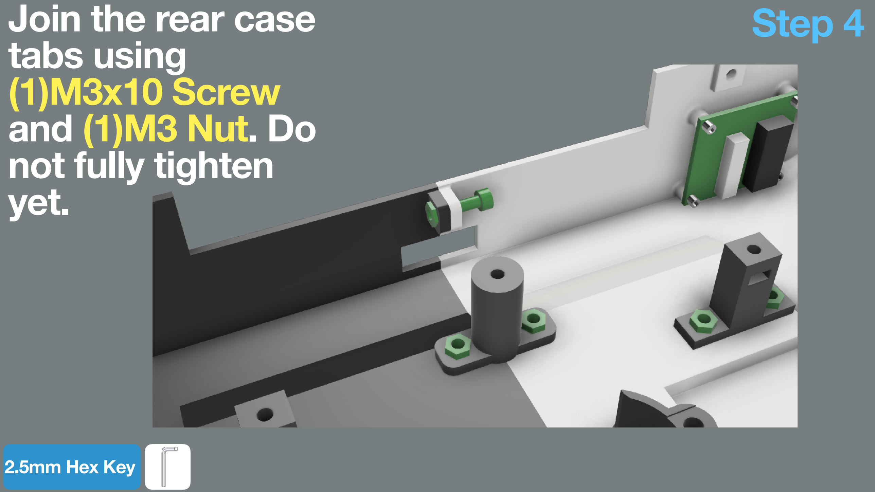
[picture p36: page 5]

## (1)M3x10 Screw and (1)M3 Nut. Do not fully tighten

yet.

## Step 4

## Ensure the two side

## case pieces are aligned properly, then proceed to tighten all the Screws to securely join the two side

case pieces.

## Step 5

Ready the | Step 6

## Gearbox

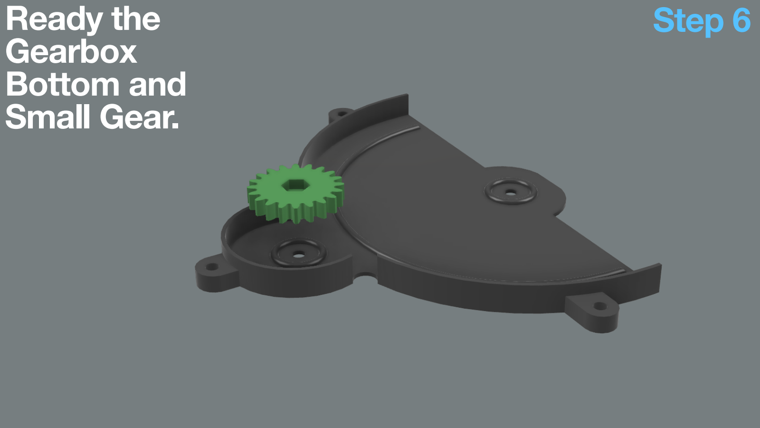
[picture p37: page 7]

## Bottom and

Small Gear.

## Insert (1)M3x8 Screw through

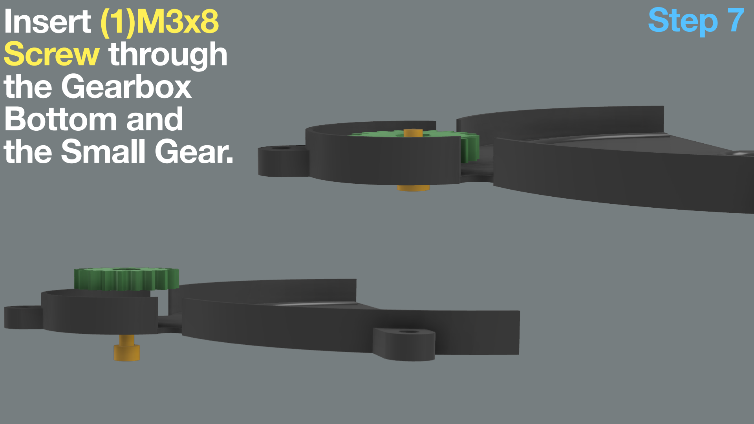
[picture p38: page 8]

## the Gearbox Bottom and

the Small Gear.

## Step 7

## Place (1)M3 Lock Nut into the recess

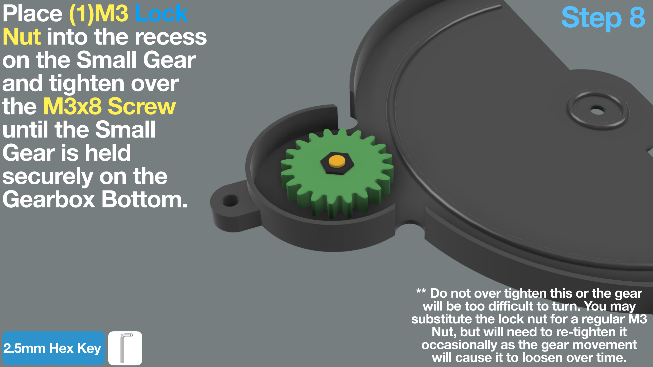
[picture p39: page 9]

## on the Small Gear and tighten over the M3x8 Screw until the Small Gear is held securely on the

Gearbox Bottom.

## Step 8

** Do not over tighten this or the gear will be too difficult to turn. You may substitute the lock nut for a regular M3 Nut, but will need to re-tighten it occasionally as the gear movement will cause it to loosen over time.

### Step 9 Align and place the Gearbox Assembly onto the (4x) Gearbox posts and insert (3)M3 Nuts into the holes in the fronts of the 3x square Gearbox

Posts.

Using | Step 10 ⁽³⁾M3x16

### Screws, secure

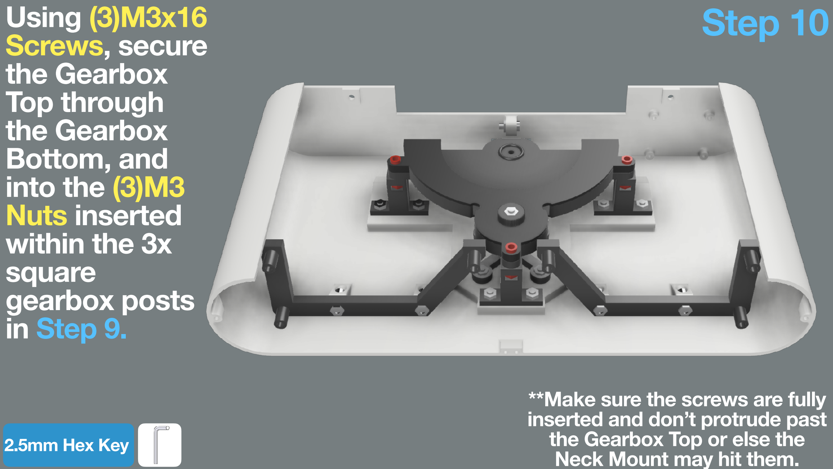
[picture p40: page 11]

### the Gearbox Top through the Gearbox Bottom, and into the (3)M3 Nuts inserted within the 3x square gearbox posts

in Step 9.

**Make sure the screws are fully inserted and don’t protrude past the Gearbox Top or else the Neck Mount may hit them.

## Using (3)M3x12 Screws and

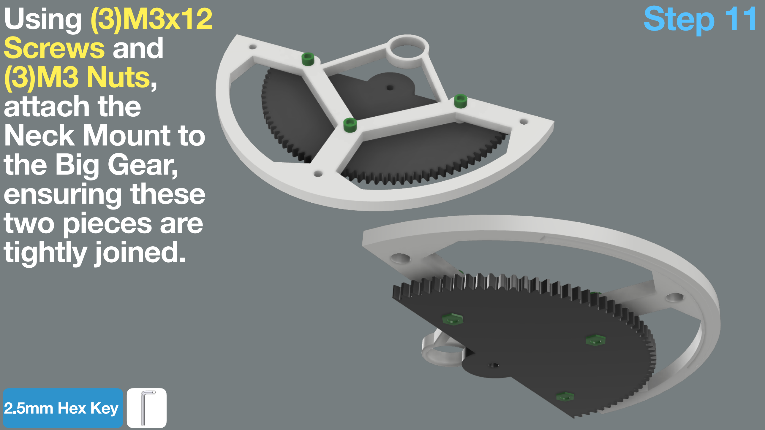
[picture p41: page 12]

(3)M3 Nuts,

## attach the Neck Mount to

the Big Gear,

## ensuring these two pieces are

tightly joined.

## Step 11

## Take the Neck Mount/Big

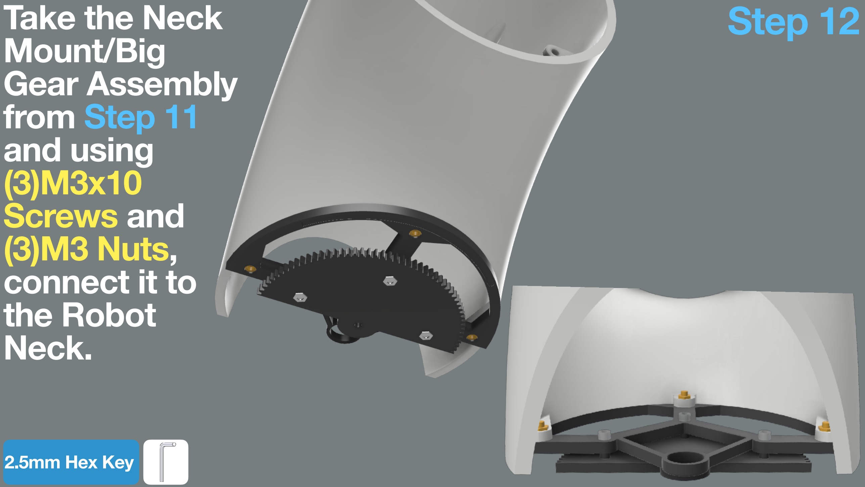
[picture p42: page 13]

## Gear Assembly from Step 11 and using

(3)M3x10

## Screws and

(3)M3 Nuts,

## connect it to the Robot

Neck.

## Step 12

## Use the provided (4)Phillips Screws

## to attach the Raspberry Pi to the back of the round LCD

display.

## Step 13

Phillips Driver

## Connect the included DSI

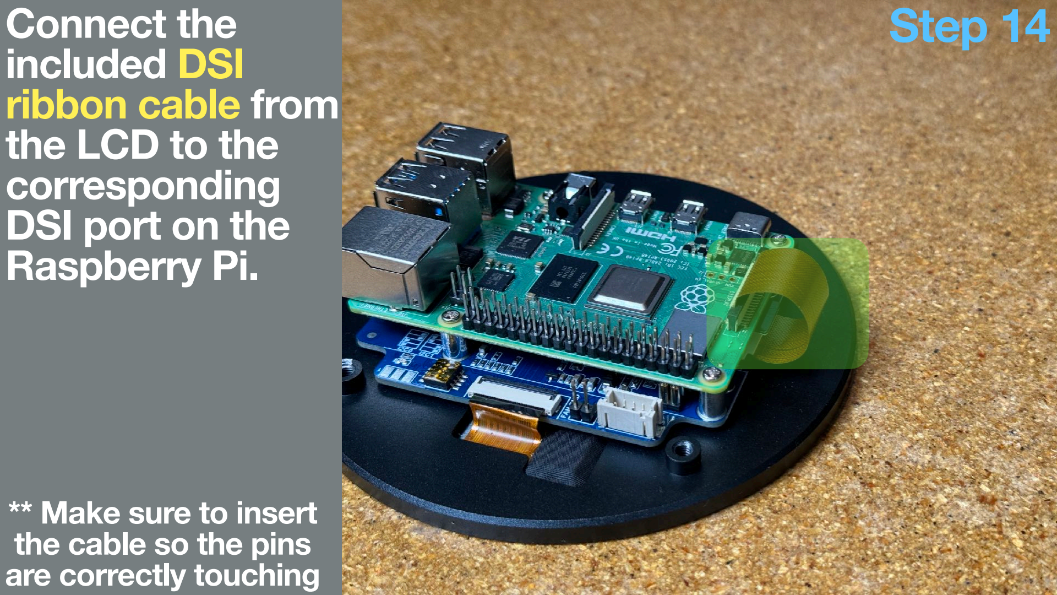
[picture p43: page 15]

## ribbon cable from the LCD to the corresponding DSI port on the

Raspberry Pi.

## Step 14

** Make sure to insert
the cable so the pins
are correctly touching

## Carefully insert the WM8960

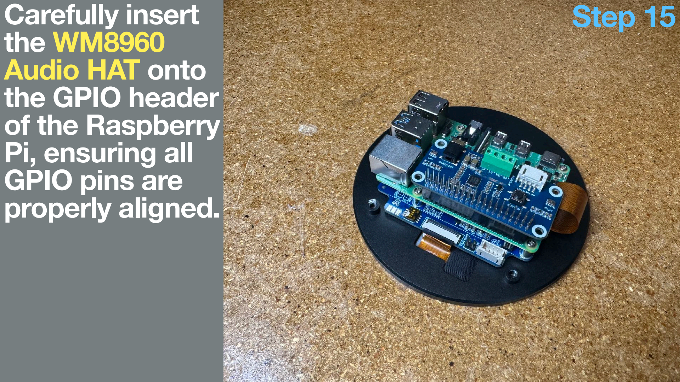
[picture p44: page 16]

## Audio HAT onto the GPIO header of the Raspberry Pi, ensuring all GPIO pins are

properly aligned.

## Step 15

## Use the included 4-pin

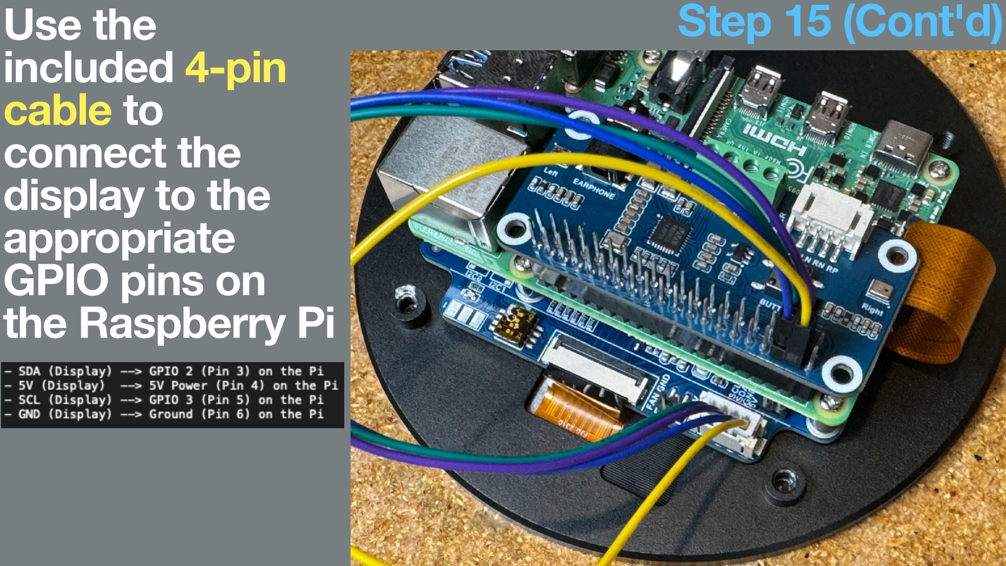
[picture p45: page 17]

## cable to connect the display to the appropriate GPIO pins on the Raspberry Pi

## Step 15 (Cont'd)

## Connect the right angle USB-C

## adapter to the power port on the Pi, this will allow for the Pi's power supply to be plugged in without

hitting the neck.

## Step 16

## Step 17

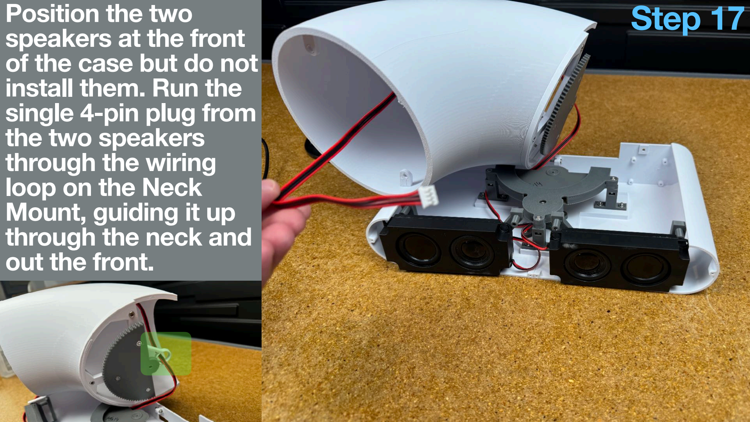
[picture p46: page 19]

### Position the two speakers at the front of the case but do not install them. Run the single 4-pin plug from the two speakers through the wiring loop on the Neck Mount, guiding it up through the neck and

out the front.

### With the plug hanging out from

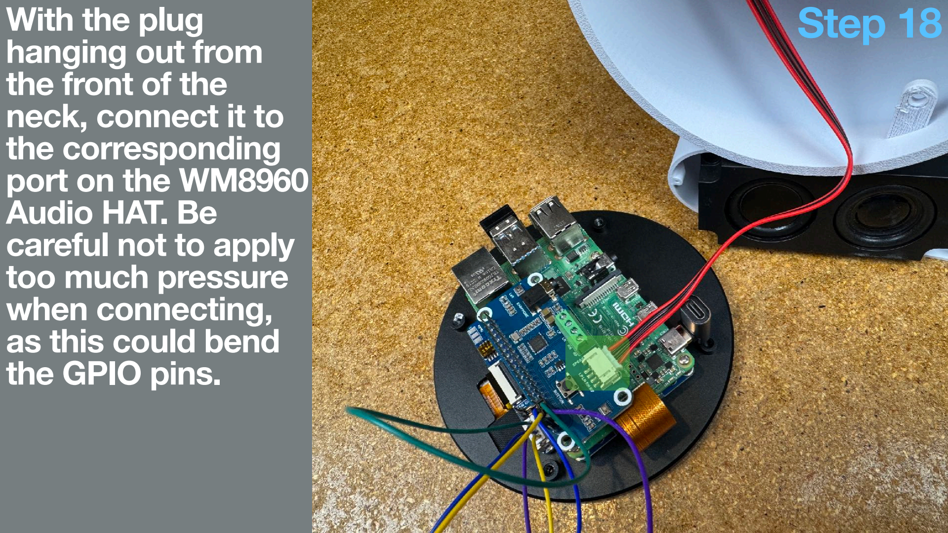
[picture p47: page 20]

### the front of the neck, connect it to the corresponding port on the WM8960 Audio HAT. Be careful not to apply too much pressure

when connecting,

### as this could bend

the GPIO pins.

## Step 18

## Step 19

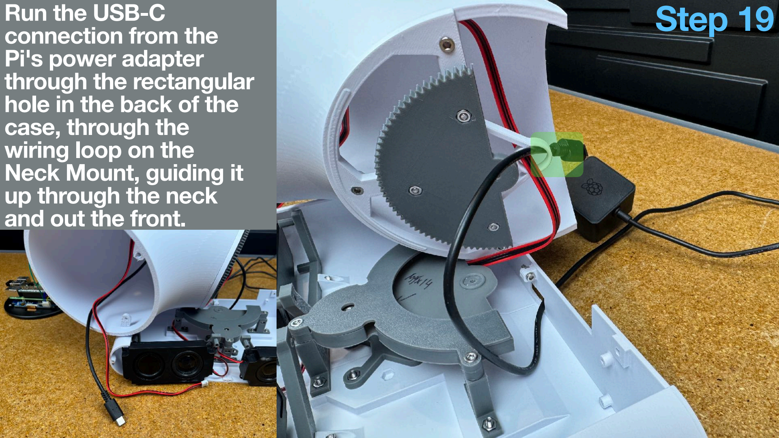
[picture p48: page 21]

Run the USB-C
connection from the
Pi's power adapter
through the rectangular
hole in the back of the
case, through the
wiring loop on the
Neck Mount, guiding it
up through the neck
and out the front.

## With the plug hanging out from

## the front of the neck, connect it to the right angle USB-C adapter that was installed in Step 16

## Step 20

## Step 21

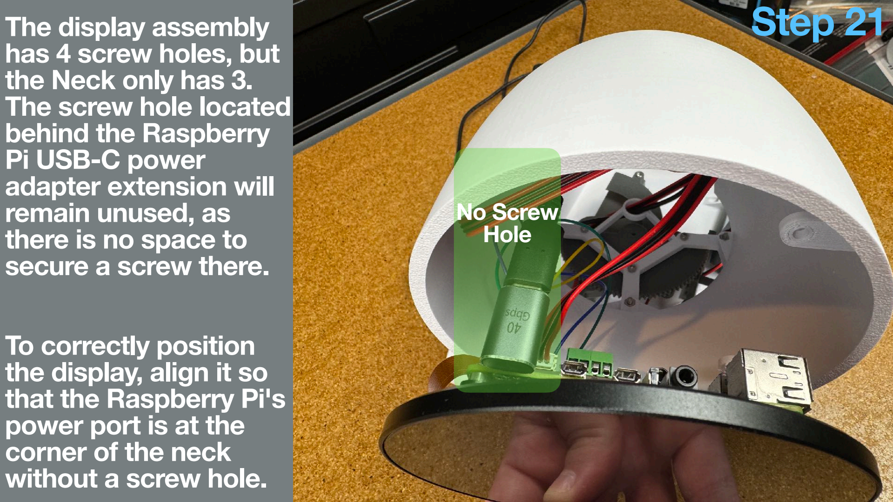
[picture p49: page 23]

The display assembly
has 4 screw holes, but
the Neck only has 3.
The screw hole located
behind the Raspberry
Pi USB-C power
adapter extension will
remain unused, as
there is no space to
secure a screw there.

To correctly position
the display, align it so
that the Raspberry Pi's
power port is at the
corner of the neck
without a screw hole.

No Screw
Hole

## Step 22

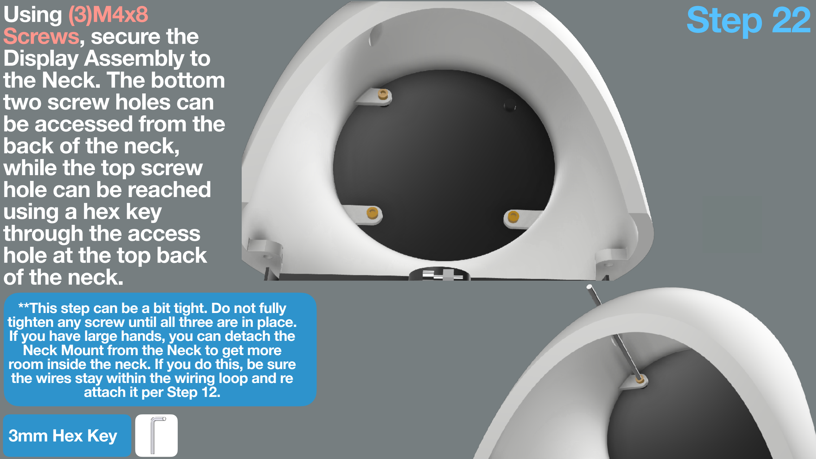
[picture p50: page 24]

**This step can be a bit tight. Do not fully tighten any screw until all three are in place. If you have large hands, you can detach the Neck Mount from the Neck to get more room inside the neck. If you do this, be sure the wires stay within the wiring loop and re attach it per Step 12.

Using (3)M4x8
Screws, secure the
Display Assembly to
the Neck. The bottom
two screw holes can
be accessed from the
back of the neck,
while the top screw
hole can be reached
using a hex key
through the access
hole at the top back
of the neck.

3mm Hex Key

## Step 23

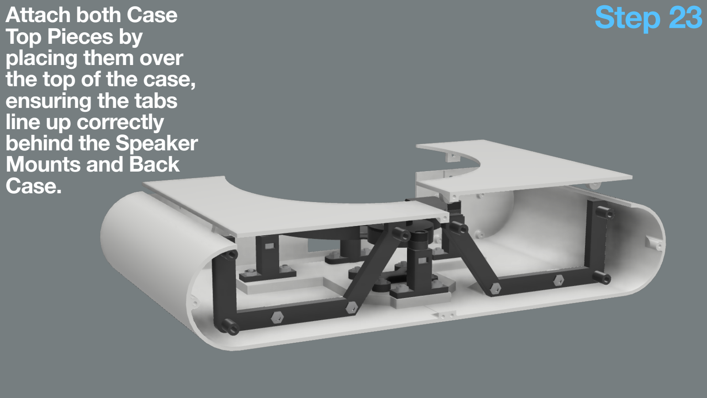
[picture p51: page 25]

Attach both Case
Top Pieces by
placing them over
the top of the case,
ensuring the tabs
line up correctly
behind the Speaker
Mounts and Back
Case.

## Step 24

With the Top Case Pieces in place, insert (1)M3x12 Screw through the hole in the back of the case piece, through the Top Case Piece, tightening it to secure the back of the Top Case Piece. There are no M3 Nuts holding the top case piece on, as they would be too difficult to secure in place.

## Repeat The Previous Step for the opposite

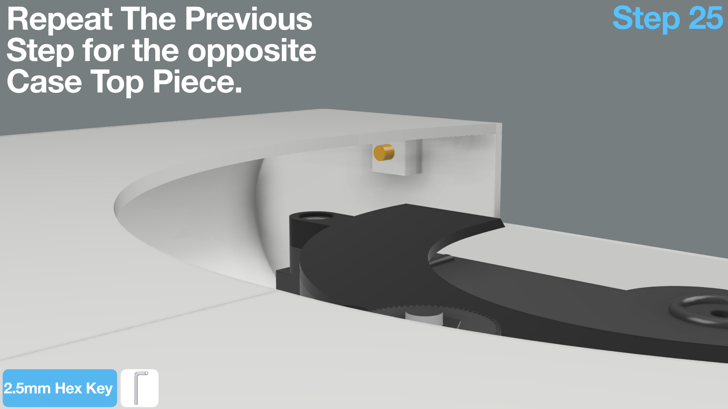
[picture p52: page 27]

Case Top Piece.

## Step 25

## Attach a speaker to the Speaker

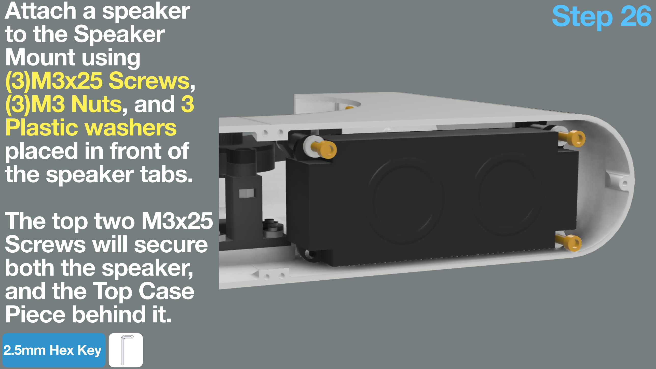
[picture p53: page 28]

## Mount using

(3)M3x25 Screws,

## (3)M3 Nuts, and 3 Plastic washers placed in front of

the speaker tabs.

## The top two M3x25 Screws will secure

both the speaker,

## and the Top Case

Piece behind it.

## Step 26

## Repeat The Previous Step for the opposite

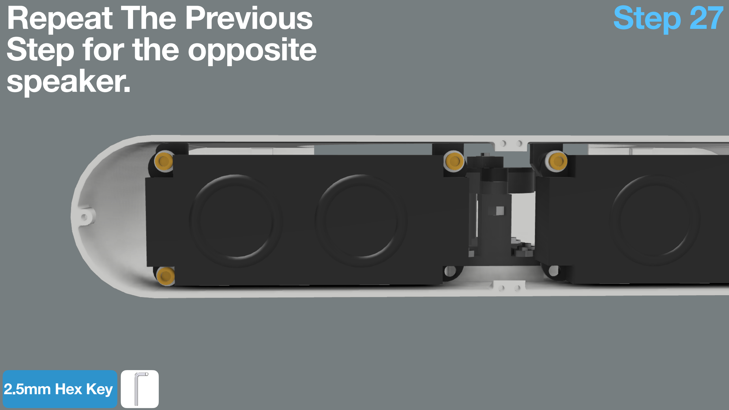
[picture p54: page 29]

speaker.

## Step 27

## Step 28

Take the Neck/Display
assembly and slide the
Big Gear into the
Gearbox until it
meshes with the Small
Gear.

**Note how the Big Gear and Small Gear mesh. The Big Gear goes between the Gearbox Top and Gearbox Bottom, while the Neck Mount, rests on top of the Gearbox Top.

## Step 29

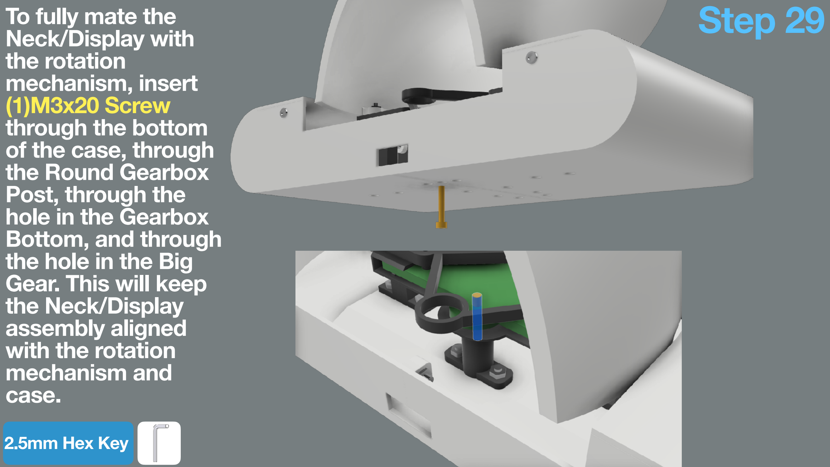
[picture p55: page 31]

To fully mate the
Neck/Display with
the rotation
mechanism, insert
(1)M3x20 Screw
through the bottom
of the case, through
the Round Gearbox
Post, through the
hole in the Gearbox
Bottom, and through
the hole in the Big
Gear. This will keep
the Neck/Display
assembly aligned
with the rotation
mechanism and
case.

Place (1)M3 Nut
inside the Gear Top
Cover, and tighten it
over the M3x20
Screw sticking out
of the Big Gear. Do
not over tighten this
Nut or you will not
be able to spin the
rotation mechanism.

This will keep the
Neck/Display
assembly attached
to the rotation
mechanism and
case

## Step 30

## Step 31

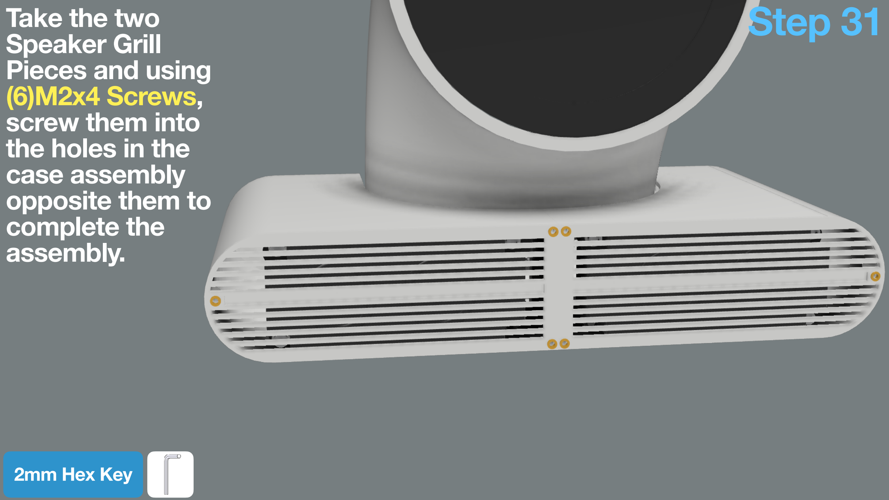
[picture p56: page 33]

Take the two
Speaker Grill
Pieces and using
(6)M2x4 Screws,
screw them into
the holes in the
case assembly
opposite them to
complete the
assembly.

2mm Hex Key

## This Concludes the build instructions

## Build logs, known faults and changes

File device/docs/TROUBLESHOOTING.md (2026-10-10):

# Troubleshooting

Run these on the Pi to see what needs attention:

```bash
sudo peri-config status
sudo /opt/peri/scripts/verify.sh
sudo journalctl -u peri-server -u peri-kiosk -n 80 --no-pager
```

| Problem | Check or fix |
|---|---|
| Cannot connect over SSH | Check the Pi's power and network. Try its IP address instead of `peri.local`. SSH must be enabled in the OS. |
| Blank display | Check the DSI ribbon and display power with power disconnected. After installation, reboot and run `sudo peri-kiosk status`. |
| Text console instead of Peri | Run `sudo peri-kiosk start`. To start it automatically on boot, run `sudo peri-kiosk enable` and reboot. |
| Interface appears on an HDMI screen | Disconnect the HDMI monitor and reboot. |
| Interface stopped responding | Run `sudo peri-kiosk restart`. Check the server log if it happens again. |
| No sound or microphone | Run `sudo /opt/peri/scripts/audio-test.sh`. Check HAT seating, speaker connections and volume. A fresh Legacy OS image requires vendor audio drivers. |
| Peri interrupts itself | Lower volume. In settings, change **Talk over Peri** to **Tap only**. |
| API key or connection error | Run `sudo peri-config key-check`. Check internet access, the Pi's clock, API billing and your key. Replace the key using the method in [setup](../INSTALL.md#4-add-your-api-key). |
| Nano not detected / unwanted head settings | Expected for this enclosure: the optional Nano does not connect to the Pi. Run `sudo peri-config set PERI_HEAD_DRIVER none` if you used older setup instructions. Conversation works without the Arduino. |
| Optional Arduino has no power or movement | Check its separate supply and the [standalone sweep wiring](../firmware/README.md). Upload `peri_sweep.ino` from your computer; the other sketch, `peri_head.ino`, waits for serial commands and will not sweep from power alone. Head movement is still unverified. |
| Optional head moves in the wrong direction or hits a cover | Turn off its separate supply. Inspect the gear mesh, wiring and cable clearance; adjust direction/range in its standalone sketch. Pi head settings cannot control this Arduino. |
| Need to retry installation | From `~/device`, run `sudo bash ./install.sh --yes --head none`. Existing settings and the API key are retained. |

The installation log is `/var/log/peri-install.log`. To undo installation, use the [removal instructions](../INSTALL.md#update-or-remove).

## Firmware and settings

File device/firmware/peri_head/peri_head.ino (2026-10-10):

/*
 * peri_head.ino - serial-controlled stepper controller for the Peri neck.
 *
 * Board : Arduino Nano (ATmega328P), 28BYJ-48 through a ULN2003 board on D8..D11 (IN1..IN4).
 * Needs : nothing but the Arduino core (Serial, micros, millis, port registers, math). No libraries.
 * Spec  : the serial protocol v1 and the motion algorithm in ../README.md are normative; this file implements them.
 *
 * Structure (everything is non-blocking; loop() never waits):
 *   loop() = stepIfDue()      issue at most one step when its time has come
 *          + housekeeping()   asynchronous "P" lines and the coil watchdog
 *          + serviceSerial()  consume at most one input byte; run a complete line when there is time for it
 * Slow work (running a command, printing) is only started when it will be finished before the next step is due,
 * so it can never make a step late.
 */

// ---- configuration ------------------------------------------------------------------------------------------
#define FW_VERSION       "1.0.0"
#define HALF_STEPS_REV   "4076"                  // banner only: nominal half-steps per output-shaft rev (4075.7728)

static const int16_t  MAX_ABS_POS = 3500;        // |target| limit, half-steps (about 60 deg of neck at 5.1:1)
static const int16_t  MAX_SPS     = 1200;        // vmax is clamped to this (half-steps/s); the motor skips above ~1000
static const int16_t  MAX_ACCEL   = 6000;        // accel is clamped to this (half-steps/s^2)
static const uint8_t  LINE_MAX    = 47;          // longest accepted input line (characters); the buffer is one more
static const uint32_t PUSH_MS     = 100;         // period of the asynchronous "P" lines while moving
static const uint32_t WATCHDOG_MS = 30000UL;     // release idle, energised coils after this long
static const uint8_t  TX_NEEDED   = 34;          // free TX bytes needed before printing (longest line is the 32-byte banner)
static const int32_t  SLOW_JOB_US = 500;         // upper bound of one slow job: run a command (sqrt, divisions) + print a line
static const uint8_t  COILS       = 0x0F;        // D8..D11 = PB0..PB3 = ULN2003 IN1..IN4 = low nibble of PORTB

static_assert(1000000L / MAX_SPS > SLOW_JOB_US, "the step interval at MAX_SPS must leave room for a slow job");
#if defined(SERIAL_TX_BUFFER_SIZE) && SERIAL_TX_BUFFER_SIZE < 64
#error "peri_head waits for TX_NEEDED free bytes before it prints: it needs the 64 byte TX buffer of the ATmega328P"
#endif

// Half-step table, indexed by pos & 7 (bit0 = IN1 ... bit3 = IN4). Same as the table in the README.
// "pos & 7" is the correct phase for negative positions too (two's complement: -1 & 7 == 7).
static const uint8_t HALF[8] = {0x1, 0x3, 0x2, 0x6, 0x4, 0xC, 0x8, 0x9};

// ---- state ----------------------------------------------------------------------------------------------------
static int16_t  pos, target;         // half-steps; pos 0 = wherever the head was when the Nano reset
static bool     moving;              // a move (including its braking ramp) is in progress
static bool     energised;           // coils are driven (low nibble of PORTB is a half-step pattern)
static int8_t   dir = 1;             // direction of the current move: +1 / -1
static int32_t  n;                   // Austin ramp counter: >0 accelerating/cruising, <0 braking, 0 = ramp start/end
static float    cn, c0, cmin;        // current interval, first-step interval, cruise interval  [microseconds]
static float    accel, stopK;        // accel [half-steps/s^2]; stopK = 5e11 / accel (see stopSteps)
static uint32_t lastStepUs, stepUs;  // the next step is due at lastStepUs + stepUs (micros(), wraps every 71 min)
static uint32_t lastPushMs;          // last periodic "P"
static uint32_t lastCmdMs;           // last accepted motion command or end of move (watchdog reference)
static bool     pushDue;             // a "P" (move finished / coils released) is still to be sent

static char     line[LINE_MAX + 1];  // input line being assembled
static uint8_t  lineLen;
static bool     lineOverflow;        // the current line is too long: discard it, answer ERR OVERFLOW at its end
static bool     lineReady;           // a complete line is waiting for a moment when it can be run

static const char BANNER[]       = "PERI-HEAD 1 " HALF_STEPS_REV " READY fw=" FW_VERSION "\n";
static const char ERR_UNKNOWN[]  = "ERR UNKNOWN\n";
static const char ERR_ARGS[]     = "ERR ARGS\n";
static const char ERR_RANGE[]    = "ERR RANGE\n";
static const char ERR_BUSY[]     = "ERR BUSY\n";
static const char ERR_OVERFLOW[] = "ERR OVERFLOW\n";

// ---- coils --------------------------------------------------------------------------------------------------
// Direct port writes: only the low nibble of PORTB is touched (D12/D13 and the crystal pins keep their state).
static void drive() {
  PORTB = (PORTB & ~COILS) | HALF[pos & 7];
  energised = true;
}

static void release() {
  PORTB &= ~COILS;
  energised = false;
}

// ---- output -------------------------------------------------------------------------------------------------
static void say(const char *s) { Serial.write(s, strlen(s)); }

static char *putNum(char *p, int16_t v) {         // append a signed decimal number, no printf needed
  uint16_t u = (v < 0) ? -v : v;
  char t[5];
  uint8_t k = 0;
  if (v < 0) *p++ = '-';
  do { t[k++] = '0' + u % 10; u /= 10; } while (u);
  while (k) *p++ = t[--k];
  return p;
}

static void sendState() {                         // P <pos> <target> <moving> <energised>
  char b[24], *p = b;
  *p++ = 'P'; *p++ = ' ';
  p = putNum(p, pos);    *p++ = ' ';
  p = putNum(p, target); *p++ = ' ';
  *p++ = moving ? '1' : '0';    *p++ = ' ';
  *p++ = energised ? '1' : '0'; *p++ = '\n';
  Serial.write(b, p - b);
}

static bool txRoom() { return Serial.availableForWrite() >= TX_NEEDED; }   // printing then never blocks

// True when a slow job started now is done before the next step is due (always true when not moving; at the top
// speed the interval is 833 us, so the job has to start within its first 333 us).
static bool slack() {
  return !moving || (int32_t)stepUs - (int32_t)(micros() - lastStepUs) > SLOW_JOB_US;
}

// ---- motion: step-interval recurrence (README "Motion algorithm") ---------------------------------------------
// Steps needed to stop from the current speed:  stops = trunc(v^2 / 2a)  with v = 1e6 / cn (cn in microseconds),
// i.e. 1e12 / (2 a cn^2) = stopK / cn^2  with stopK = 5e11 / a.  One float division per step instead of two.
static int32_t stopSteps() {
  return (n == 0) ? 0 : (int32_t)(stopK / (cn * cn));
}

// Called right after every step, and once to start a move. Sets n, dir, cn and stepUs for the next step,
// or ends the move.
static void computeNewInterval() {
  int16_t dist  = target - pos;
  int32_t stops = stopSteps();

  if (dist == 0 && stops <= 1) {                  // arrived
    n = 0; cn = 0; moving = false;
    return;
  }
  if (dist > 0) {
    if (n > 0)      { if (stops >= dist  || dir < 0) n = -stops; }    // start braking (or turn round)
    else if (n < 0) { if (stops <  dist  && dir > 0) n = -n; }        // target moved away: accelerate again
  } else {
    if (n > 0)      { if (stops >= -dist || dir > 0) n = -stops; }
    else if (n < 0) { if (stops <  -dist && dir < 0) n = -n; }
  }
  // Braking is the same recurrence with a negative n (4n+1 < 0 makes cn grow); n counts up from -stops to 0.
  if (n == 0) {
    cn = c0;                                      // start from rest, or restart after braking to a halt
    dir = (dist > 0) ? 1 : -1;
  } else {
    cn = cn - 2.0f * cn / (4.0f * n + 1.0f);      // Austin eq. 13: cn = cn-1 - 2 cn-1 / (4n + 1)
    if (cn < cmin && n > 0) n--;                  // cruising: hold n, so a later change of vmax/accel continues smoothly
  }
  if (cn < cmin) cn = cmin;                       // never faster than vmax (also for the first step at very low vmax)
  n++;
  stepUs = (uint32_t)(cn + 0.5f);
}

static void stepIfDue() {
  if (!moving) return;
  uint32_t now = micros();
  if ((uint32_t)(now - lastStepUs) < stepUs) return;   // unsigned difference: correct across the micros() rollover
  pos += dir;                                     // at most one step per loop pass, whatever the lateness
  drive();
  lastStepUs += stepUs;                           // schedule from the ideal time of this step, not from "now"
  computeNewInterval();
  if (!moving) {
    lastCmdMs = millis();                         // holding starts now: the 30 s watchdog counts from here
    pushDue = true;                               // one "P" with moving 0
  } else if ((uint32_t)(now - lastStepUs) > (stepUs >> 3)) {
    lastStepUs = now;                             // more than 1/8 interval late: re-anchor instead of catching up with a
  }                                               // short interval (so no gap is ever shorter than 7/8 of the scheduled one)
}

// ---- commands -----------------------------------------------------------------------------------------------
// Decimal integer with an optional leading '-'. Saturates instead of overflowing, so absurdly long numbers
// still parse (and are then rejected by the range check).
static bool parseInt(const char *s, int32_t *out) {
  bool neg = (*s == '-');
  int32_t v = 0;
  if (neg) s++;
  if (!*s) return false;
  for (; *s; s++) {
    if (*s < '0' || *s > '9') return false;
    if (v < 100000000L) v = v * 10 + (*s - '0');
  }
  *out = neg ? -v : v;
  return true;
}

// T: (re)target. Energises the coils, starts a move from rest or retargets the running one.
static void cmdMove(int16_t tgt, int16_t vmax, int16_t acc) {
  float a = acc;
  if (n != 0 && a != accel) {                     // accel changed mid-ramp: keep the speed (v^2 = 2 a n), rescale n
    int32_t old = n;
    n = (int32_t)((float)n * accel / a);
    if (n == 0) n = (old > 0) ? 1 : -1;
  }
  accel = a;
  stopK = 5e11f / a;
  c0    = 0.676f * sqrt(2.0f / a) * 1e6f;         // first-step interval incl. Austin's correction, microseconds
  cmin  = 1e6f / vmax;
  target = tgt;
  if (!energised) drive();
  if (!moving && target != pos) {
    moving = true;
    n = 0;
    lastStepUs = micros();                        // first step comes c0 after the command
    lastPushMs = millis();
    computeNewInterval();
  }                                               // moving: the running ramp just sees the new target next step
  lastCmdMs = millis();
}

// S: brake to a stop. The recurrence decides about braking after the next step, and that step is already
// scheduled, so the stopping point is stops + 1 steps ahead: then dist == stops holds all along the ramp and
// the move ends exactly on the target (without the +1 it overshoots by one step and comes back).
static void cmdStop() {
  if (moving) target = pos + dir * (stopSteps() + 1);
  lastCmdMs = millis();
}

// X: stop at once, coils stay energised.
static void cmdHalt() {
  moving = false; n = 0; cn = 0;
  target = pos;
  lastCmdMs = millis();
}

// Splits on single spaces (empty tokens are kept, so double spaces are malformed), then dispatches.
static void execLine(char *s) {
  char *arg[4];
  uint8_t argc = 0;
  for (;;) {
    if (argc < 4) arg[argc] = s;
    argc++;
    while (*s && *s != ' ') s++;
    if (!*s) break;
    *s++ = 0;
  }
  const char *cmd = arg[0];

  if (!strcmp(cmd, "T")) {
    int32_t t, v, a;
    if (argc != 4 || !parseInt(arg[1], &t) || !parseInt(arg[2], &v) || !parseInt(arg[3], &a)) { say(ERR_ARGS); return; }
    if (v < 1 || a < 1 || t > MAX_ABS_POS || t < -MAX_ABS_POS)                                { say(ERR_RANGE); return; }
    cmdMove(t, v > MAX_SPS ? MAX_SPS : v, a > MAX_ACCEL ? MAX_ACCEL : a);
    sendState();
  } else if (!strcmp(cmd, "HELLO")) {
    if (argc != 1) say(ERR_ARGS); else say(BANNER);
  } else if (!strcmp(cmd, "Q")) {
    if (argc != 1) say(ERR_ARGS); else sendState();
  } else if (!strcmp(cmd, "S") || !strcmp(cmd, "X")) {
    if (argc != 1) { say(ERR_ARGS); return; }
    if (cmd[0] == 'S') cmdStop(); else cmdHalt();
    sendState();
  } else if (!strcmp(cmd, "Z") || !strcmp(cmd, "R")) {
    if (argc != 1) { say(ERR_ARGS); return; }
    if (moving)    { say(ERR_BUSY); return; }
    if (cmd[0] == 'Z') {
      pos = 0; target = 0;
      if (energised) drive();                     // keep "phase = pos & 7" true for the new numbering
    } else {
      release();
    }
    lastCmdMs = millis();
    sendState();
  } else {
    say(ERR_UNKNOWN);
  }
}

// ---- main loop parts ----------------------------------------------------------------------------------------
static void housekeeping() {
  if (!(moving || energised || pushDue) || !txRoom() || !slack()) return;
  uint32_t ms = millis();
  if (pushDue) {
    pushDue = false;
    sendState();
  } else if (moving) {
    if ((uint32_t)(ms - lastPushMs) >= PUSH_MS) { lastPushMs = ms; sendState(); }
  } else if ((uint32_t)(ms - lastCmdMs) >= WATCHDOG_MS) {   // idle with energised coils: never leave them on
    release();
    sendState();
  }
}

// Collecting a byte is cheap (one per pass: at 115200 baud a byte arrives every 87 us, a pass takes far less).
// Running the finished line is the slow part: it waits until there is time for it, and until a pending "P" is out.
static void serviceSerial() {
  if (lineReady) {
    if (pushDue || !txRoom() || !slack()) return;
    if (lineOverflow) say(ERR_OVERFLOW);          // exactly one reply per line, sent when the line ends
    else { line[lineLen] = 0; execLine(line); }
    lineLen = 0;
    lineOverflow = false;
    lineReady = false;
    return;
  }
  if (!Serial.available()) return;
  char c = Serial.read();
  if (c == '\r') return;                          // ignored anywhere in a line
  if (c == '\n') lineReady = true;
  else if (lineLen < LINE_MAX) line[lineLen++] = c ? c : '?';   // a NUL would silently cut the line short
  else lineOverflow = true;
}

void setup() {
  PORTB &= ~COILS;                                // coils off before the pins become outputs
  DDRB  |= COILS;
  Serial.begin(115200);
  say(BANNER);
}

void loop() {
  stepIfDue();
  housekeeping();
  serviceSerial();
}

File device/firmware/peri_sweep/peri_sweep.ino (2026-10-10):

/*
 * Experimental standalone head sweep for Peri.
 * Nano (ATmega328P) -> ULN2003 IN1..IN4 on D8..D11 -> 5 V 28BYJ-48.
 * Uses separate power; no Pi, serial commands or extra libraries required.
 *
 * Center the head with power OFF before every startup/reset. There is no
 * position sensor or homing: zero is wherever the head starts. Movement and
 * clearance have not been verified on the physical Peri. Start at +/-5 degrees.
 * Disconnect the Arduino's own supply to stop; Pi shutdown cannot stop it.
 */
#include <Arduino.h>

// Adjust only after checking the mechanism and wiring on your own build.
static constexpr float SWEEP_DEGREES = 5.0f;      // estimated neck angle on each side
static const bool INVERT_DIRECTION = false;  // swap left/right if needed
static const unsigned long STARTUP_PAUSE_MS = 3000;
static const unsigned long PAUSE_MS = 2000;
static const unsigned int STEP_INTERVAL_US = 4000; // slower = larger interval

// Nominal gearing from the existing Peri motor configuration; calibrate physically.
static constexpr float HALF_STEPS_PER_MOTOR_REV = 4075.7728f;
static constexpr float MOTOR_REVS_PER_NECK_REV = 5.1f;
static const int16_t SWEEP_STEPS = static_cast<int16_t>(
    SWEEP_DEGREES * HALF_STEPS_PER_MOTOR_REV * MOTOR_REVS_PER_NECK_REV / 360.0f + 0.5f);
static_assert(SWEEP_DEGREES > 0.0f && SWEEP_DEGREES <= 20.0f,
              "Use a small sweep, never larger than the measured physical clearance");
static_assert(STEP_INTERVAL_US >= 4000 && STEP_INTERVAL_US <= 16000,
              "Use a slow step interval between 4000 and 16000 microseconds");

static const uint8_t PINS[4] = {8, 9, 10, 11}; // IN1, IN2, IN3, IN4
static const uint8_t HALF[8] = {0x1, 0x3, 0x2, 0x6, 0x4, 0xC, 0x8, 0x9};
static int16_t position = 0;
static uint8_t phase = 0;

static void releaseCoils() {
  for (uint8_t i = 0; i < 4; ++i) digitalWrite(PINS[i], LOW);
}

static void moveTo(int16_t target) {
  while (position != target) {
    const int8_t direction = target > position ? 1 : -1;
    const int8_t motorDirection = INVERT_DIRECTION ? -direction : direction;
    phase = static_cast<uint8_t>((phase + (motorDirection > 0 ? 1 : 7)) & 7);
    for (uint8_t i = 0; i < 4; ++i) {
      digitalWrite(PINS[i], (HALF[phase] & (1U << i)) ? HIGH : LOW);
    }
    delayMicroseconds(STEP_INTERVAL_US);
    position += direction;
  }
  releaseCoils(); // no holding current during pauses; recenter if the head is moved
  delay(PAUSE_MS);
}

void setup() {
  for (uint8_t i = 0; i < 4; ++i) {
    digitalWrite(PINS[i], LOW);
    pinMode(PINS[i], OUTPUT);
  }
  delay(STARTUP_PAUSE_MS); // powers up quietly, then starts moving automatically
}

void loop() {
  moveTo(-SWEEP_STEPS); // left, pause
  moveTo(0);            // middle, pause
  moveTo(SWEEP_STEPS);  // right, pause
  moveTo(0);            // middle, pause; repeat without jumping across the full arc
}

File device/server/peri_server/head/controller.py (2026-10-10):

"""HeadController: the neck as the rest of the server sees it (docs/API.md section 4).

Frames: drivers report degrees relative to *their* zero (the position at connect / last ``set_zero``). The controller keeps
``base`` so that ``angle = base + driver_position`` is the calibrated neck angle (0 = facing straight ahead, positive = the
head's right). When a driver (re)connects its zero is wherever the neck happens to be, so ``base`` is set to the last known
angle (persisted in calibration.json) - the neck is assumed not to move while the server is down.
"""
from __future__ import annotations

import asyncio
import logging
from dataclasses import dataclass
from typing import Any, Callable, Dict, List, Mapping, Optional

from ..errors import ApiError
from ..util import clamp
from .calibration import CalibrationStore
from .clock import RealClock
from .drivers.base import DriverState, HeadDriver
from .gestures import MIN_LEG_DEG, ScheduledLeg, plan_gesture, schedule, total_duration
from .profile import trapezoid_time

log = logging.getLogger("peri.head")

NUDGE_SPEED_DPS = 6.0        # calibration nudges are deliberately slow
MIN_SPEED_DPS = 0.5
POLL_S = 0.02                # how often a gesture leg checks whether the driver has finished


@dataclass(frozen=True)
class HeadLimits:
    """Static motion limits from the environment (docs/API.md section 8)."""

    max_speed_dps: float = 16.0
    accel_dps2: float = 40.0
    hard_limit_deg: float = 25.0
    release_after_s: float = 2.5


StateListener = Callable[[Dict[str, Any]], None]


class HeadController:
    def __init__(self, driver: HeadDriver, settings: Callable[[], Mapping[str, Any]], limits: HeadLimits,
                 calibration: CalibrationStore, clock: Optional[Any] = None) -> None:
        self.driver = driver
        self._settings = settings
        self.limits = limits
        self.calibration = calibration
        self._clock = clock if clock is not None else RealClock()
        self._base = 0.0
        self._last_angle = calibration.data.angle_deg
        self._cmd_target: Optional[float] = None    # last commanded target (calibrated frame), echoed while moving
        self._epoch = -1
        self._was_moving = False
        self._seq: Optional["asyncio.Task[None]"] = None
        self._release_task: Optional["asyncio.Task[None]"] = None
        self._listeners: List[StateListener] = []
        self._unsubscribe: Optional[Callable[[], None]] = None
        self._closing = False

    # ------------------------------------------------------------------------------------------- lifecycle
    async def start(self) -> None:
        self._unsubscribe = self.driver.subscribe(self._on_driver_state)
        await self.driver.start()
        self._track(self.driver.snapshot())

    async def park(self, center: bool = True) -> None:
        """Stop motion, optionally re-centre the neck (so the next power-up really starts centred) and release the coils."""
        await self._cancel_sequence()
        self._cancel_release()
        try:
            state = self.driver.snapshot()
            if center and state.connected and not state.error and self._enabled() and abs(self.angle) > 0.5:
                log.info("centring the neck (%.1f deg)", self.angle)
                travel = abs(self.angle)
                await self._move_abs(0.0, self.limits.max_speed_dps)
                await self._wait_idle(timeout=trapezoid_time(travel, self.limits.max_speed_dps, self.limits.accel_dps2) + 3.0)
            if state.connected:
                await self.driver.release()
        except Exception:
            log.exception("error while parking the neck")
        self.calibration.remember_angle(self.angle)

    async def shutdown(self, center: bool = True) -> None:
        """Park the neck and close the driver."""
        self._closing = True
        await self.park(center)
        if self._unsubscribe is not None:
            self._unsubscribe()
        await self.driver.stop()

    def add_listener(self, callback: StateListener) -> Callable[[], None]:
        """Callback with the public state dict (~10 Hz while moving, once when a move ends, on connect changes)."""
        self._listeners.append(callback)
        return lambda: self._listeners.remove(callback) if callback in self._listeners else None

    # ---------------------------------------------------------------------------------------------- state
    def _enabled(self) -> bool:
        return bool(self._settings().get("head", {}).get("enabled", True))

    @property
    def soft_limit(self) -> float:
        configured = float(self._settings().get("head", {}).get("limit_deg", 20))
        return min(configured, self.limits.hard_limit_deg)

    @property
    def angle(self) -> float:
        return self._base + self.driver.snapshot().position_deg

    def _target(self, state: Optional[DriverState] = None) -> float:
        """Where the neck is heading: the commanded target while moving (not the step-quantised one), else its angle."""
        st = state or self.driver.snapshot()
        if st.moving and self._cmd_target is not None:
            return self._cmd_target
        return self._base + st.target_deg

    def state(self) -> Dict[str, Any]:
        st = self.driver.snapshot()
        limit = self.soft_limit
        return {
            "driver": self.driver.name, "connected": st.connected, "angle": round(self._base + st.position_deg, 2),
            "target": round(self._target(st), 2), "moving": st.moving, "energized": st.energised,
            "limits": {"min": -limit, "max": limit}, "max_speed_dps": self.limits.max_speed_dps,
            "accel_dps2": self.limits.accel_dps2, "zeroed": self.calibration.data.zeroed, "error": st.error,
        }

    def status_detail(self) -> str:
        """Human hint about the driver (serial port, scanning, ...) for /api/diag."""
        return self.driver.snapshot().detail

    def body_can_move(self) -> bool:
        st = self.driver.snapshot()
        return self._enabled() and st.connected and not st.error

    def _ignored(self, reason: str) -> Dict[str, Any]:
        out = self.state()
        out["ignored"] = reason
        return out

    def _guard(self) -> Optional[str]:
        if not self._enabled():
            return "disabled"
        st = self.driver.snapshot()
        if st.error:
            return "error"
        if not st.connected:
            return "unavailable"
        return None
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

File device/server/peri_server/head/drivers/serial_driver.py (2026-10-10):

"""Head driver for the Arduino Nano running ``firmware/peri_head`` over USB serial (protocol v1, see firmware/README.md).

Design notes
* One I/O thread owns the port: it scans ``/dev/ttyUSB*``/``/dev/ttyACM*`` (or the configured port) for a device that
  answers with ``PERI-HEAD 1 ...``, then runs the session, and starts over when the link dies (unplug/replug works).
* Opening the port resets the Nano (DTR). Its bootloader (Optiboot) reboots *again* if it receives stray bytes, so after
  opening we stay silent and just listen for the boot banner; ``HELLO`` is only sent after a quiet period (in case the
  board did not reset).
* Commands are asynchronous: ``move_to`` updates the local view optimistically and waits for the matching ``P`` reply.
  ``P`` lines received while a command is outstanding and not matching it are ignored (they may predate the command).
* An unsolicited banner means the Nano reset (brown-out, DTR): the position reference is lost, ``epoch`` increases and the
  controller re-derives its calibrated angle.
"""
from __future__ import annotations

import asyncio
import glob
import logging
import os
import threading
import time
from dataclasses import dataclass, field
from typing import Any, Callable, Dict, List, Optional, Tuple

from .. import protocol
from .base import DriverState, HeadDriver, StepScale

log = logging.getLogger("peri.head")


class DriverUnavailable(RuntimeError):
    """The head is not connected (yet)."""


def default_port_lister() -> List[str]:
    """Candidate serial ports, de-duplicated by real path (``/dev/peri-head`` is a udev symlink to one of them)."""
    seen: Dict[str, str] = {}
    for pattern in ("/dev/peri-head", "/dev/ttyUSB*", "/dev/ttyACM*"):
        for path in sorted(glob.glob(pattern)):
            seen.setdefault(os.path.realpath(path), path)
    return list(seen.keys())


@dataclass
class _Cmd:
    line: str
    predicate: Callable[[protocol.PState], bool]
    future: "asyncio.Future[Optional[protocol.PState]]"
    loop: asyncio.AbstractEventLoop
    sent: bool = False
    sent_at: float = 0.0


@dataclass
class _Shared:
    """State shared between the I/O thread and the event loop (guarded by ``lock``)."""

    lock: threading.Lock = field(default_factory=threading.Lock)
    connected: bool = False
    port: str = ""
    pos: int = 0
    target: int = 0
    moving: bool = False
    energised: bool = False
    epoch: int = 0
    error: Optional[str] = None
    detail: str = ""


class SerialDriver(HeadDriver):
    name = "serial"

    HELLO_AFTER_S = 3.0      # silence after open before the first HELLO (bootloader reset window, see module docstring)
    HELLO_EVERY_S = 1.5

    def __init__(self, scale: StepScale, port: str = "", *, baud: int = 115200, scan_interval: float = 3.0,
                 boot_wait: float = 8.0, ack_timeout: float = 1.5, poll_interval: float = 1.0,
                 hello_after: Optional[float] = None, port_lister: Optional[Callable[[], List[str]]] = None,
                 serial_factory: Optional[Callable[..., Any]] = None, skip_bad_port_s: float = 60.0) -> None:
        super().__init__()
        self.scale = scale
        self._port = port
        self._baud = baud
        self._scan_interval = scan_interval
        self._boot_wait = boot_wait
        self._ack_timeout = ack_timeout
        self._poll_interval = poll_interval
        self._hello_after = self.HELLO_AFTER_S if hello_after is None else hello_after
        self._lister = port_lister or default_port_lister
        self._serial_factory = serial_factory
        self._skip_bad_port_s = skip_bad_port_s
        self._sh = _Shared()
        #: commands registered by the event loop and written, in order, by the I/O thread (FIFO = reply order)
        self._pending: List[_Cmd] = []
        self._plock = threading.Lock()
        self._stop_event = threading.Event()
        self._thread: Optional[threading.Thread] = None
        self._loop: Optional[asyncio.AbstractEventLoop] = None
        self._bad_ports: Dict[str, float] = {}

    # ------------------------------------------------------------------------------------------- lifecycle
    async def start(self) -> None:
        if self._thread is not None:
            return
        self._loop = asyncio.get_event_loop()
        self._stop_event.clear()
        self._thread = threading.Thread(target=self._main, name="peri-serial", daemon=True)
        self._thread.start()

    async def stop(self) -> None:
        self._stop_event.set()
        thread, self._thread = self._thread, None
        if thread is not None:
            await asyncio.get_event_loop().run_in_executor(None, thread.join, 3.0)

    # ---------------------------------------------------------------------------------------------- state
    def snapshot(self) -> DriverState:
        with self._sh.lock:
            sh = self._sh
            detail = sh.detail
            if not sh.connected and not detail:
                detail = "scanning for the head controller on USB serial"
            return DriverState(
                driver="serial", connected=sh.connected, position_deg=self.scale.to_deg(sh.pos),
                target_deg=self.scale.to_deg(sh.target), moving=sh.moving, energised=sh.energised, epoch=sh.epoch,
                error=sh.error, detail=detail)

    def _emit_threadsafe(self) -> None:
        loop = self._loop
        if loop is not None and not loop.is_closed():
            try:
                loop.call_soon_threadsafe(self._emit)
            except RuntimeError:  # loop closed while shutting down
                pass

    # -------------------------------------------------------------------------------------------- commands
    async def move_to(self, target_deg: float, max_dps: float, accel_dps2: float) -> None:
        steps = self.scale.to_steps(target_deg)
        line = protocol.format_move(steps, self.scale.rate_to_steps(max_dps), self.scale.rate_to_steps(accel_dps2))
        with self._sh.lock:
            if self._sh.connected:
                self._sh.target = steps
                self._sh.moving = steps != self._sh.pos
                self._sh.energised = True
        await self._command(line, lambda p: p.target == steps)

    async def halt(self) -> None:
        await self._command("S", lambda p: True)

    async def emergency_stop(self) -> None:
        await self._command("X", lambda p: not p.moving)

    async def release(self) -> None:
        await self._command("R", lambda p: not p.energised)

    async def set_zero(self) -> None:
        await self._command("Z", lambda p: p.pos == 0 and p.target == 0)
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
